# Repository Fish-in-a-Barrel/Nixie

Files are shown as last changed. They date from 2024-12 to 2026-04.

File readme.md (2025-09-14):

# Yet Another Nixie Clock

https://github.com/user-attachments/assets/0fcae77a-54a8-4b7d-9e90-6edd31807fbd

## Introduction

This is my Nixie clock project. It was created as an excuse to learn more about electronics and it touches on power circuits, microcontrollers, serial communications, and more.

The clock runs 12 IN-12A Nixie tubes that display the time and date. INS-1 tubes are used for digit separators. It also includes:
- USB-C PD power input
- Boost converter to provide 180V for the nixie tubes
- GPS module for date/time synchronization
- User-selectable timezone
- RTC module for precision timekeeping, and power-off timekeeping
- 128x32 mono OLED display for diagnostics
- Rotary encoder for user input
- I2C Driver boards for each tube

## Development Tools
**Hardware**: KiCad 8
**Firmware**: MPLAB X IDE

## Architecture
Architecture BlockDiagram

### Main Processor
A [Microchip PIC16F15224](https://ww1.microchip.com/downloads/aemDocuments/documents/MCU08/ProductDocuments/DataSheets/PIC16F15213-14-23-24-43-44-Microcontroller-Data-Sheet-40002195.pdf) 8-bit microcontroller is the main processing unit of the clock. It controls the boost converter while managing and coordinating the other hardware modules.

### Power
Power

A [Diodes Incorporated AP33772](https://www.diodes.com/assets/Datasheets/products_inactive_data/AP33772.pdf) is used to negotiate with a PD source for the input power. The AP33772 is controlled by the main MCU via I2C. The AP33772 requests 12V from the power source, which supplies the boost converter.

The AP33772 also provides a dedicated 5V power source. This is a low current source, so it is only used to drive the MCU and UI, which are needed during power-up. A separate 78L05 regulator (powered by the 12V from USB VBUS) provides 5V power to all of the other devices.

Finally, the AP33772 provides over-current and over-voltage protection features.

### User Interface
A 128x32 OLED display (driven by an [SSD1306](https://cdn-shop.adafruit.com/datasheets/SSD1306.pdf)) is used to display status and diagnostics information. A rotary encoder with detent is used to scroll through the different display pages, and to select timezone and DST support. The OLED pixel data is sent over I2C.

### Real Time Clock
A [DS3231](https://www.analog.com/media/en/technical-documentation/data-sheets/ds3231.pdf) RTC module provides an accurate time source for the clock. It is the source of the time/date displayed and is only updated if it differs from the GPS time. The RTC module is also equiped with a battery backup. This allows the clock to display time/date immediately after power-on instead of having to wait several minutes for valid GPS data. RTC data is sent over I2C.

### GPS
The [U-Blox NEO-6M](https://content.u-blox.com/sites/default/files/products/documents/NEO-6_DataSheet_%28GPS.G6-HW-09005%29.pdf) GPS module provides a reference time to initialize the RTC. The module streams standard NMEA messages to the primary MCU over UART serial. Time/date are decoded from these messages.

### Nixie Drivers
Each Nixie tube has a driver board. This board has a [Microchip PIC16F15243](https://ww1.microchip.com/downloads/aemDocuments/documents/MCU08/ProductDocuments/DataSheets/PIC16F15213-14-23-24-43-44-Microcontroller-Data-Sheet-40002195.pdf) MCU in I2C client mode receiving commands from the primary MCU. This client MCU drives the Nixie pins and provides features such as digit cross-fading and cathode maintenance.

## Project Components

### ClockController
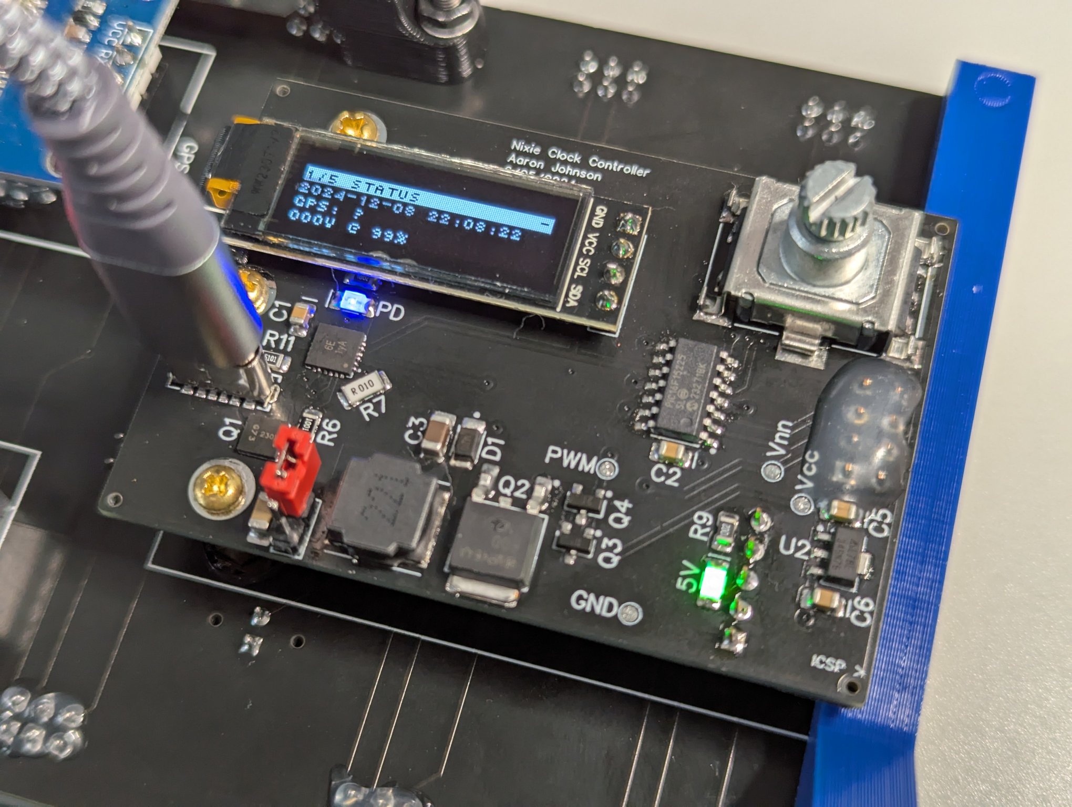
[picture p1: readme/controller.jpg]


This is the main controller board. It connects to a header on the back of the display board and has these main components:
- Primary MCU
- USB PD components
- Boost converter circuitry
- User Interface

### Hardware / Display Board
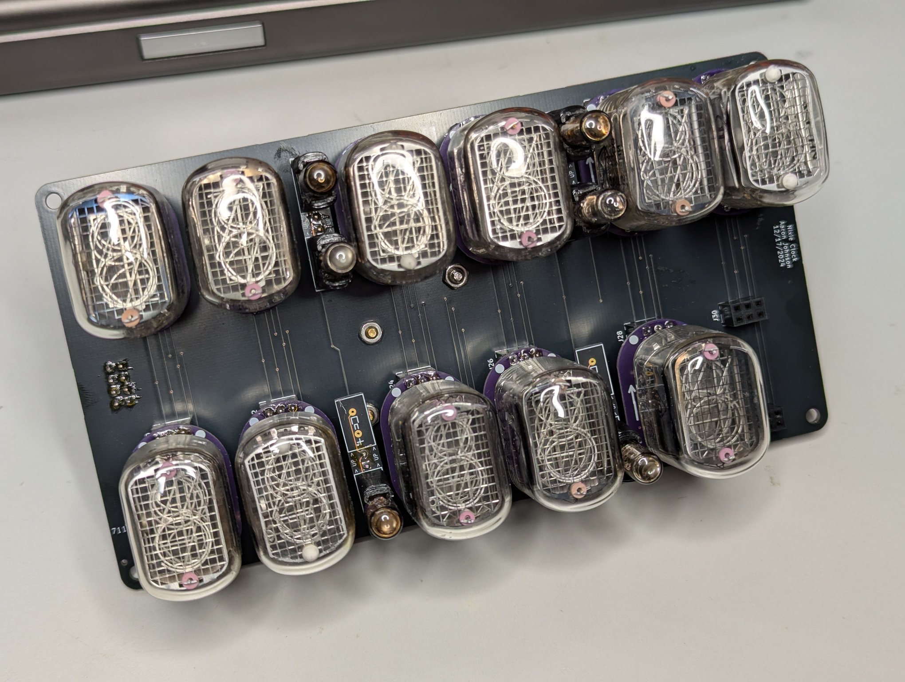
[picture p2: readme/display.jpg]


This board servers as the main support structure of the clock. The Nixie drivers connect to headers on the front of the board. The controller board, GPS, and RTC all connect to the back of the board.

### NixieDriver
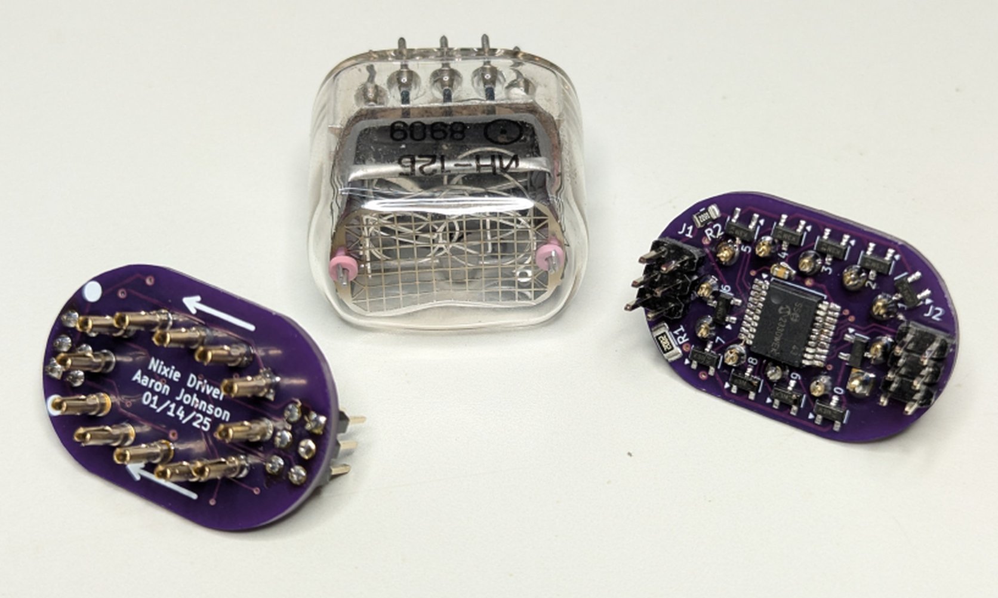
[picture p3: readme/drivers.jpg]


The driver board for each individual IN-12 Nixie tube.

### NixieDriverTester
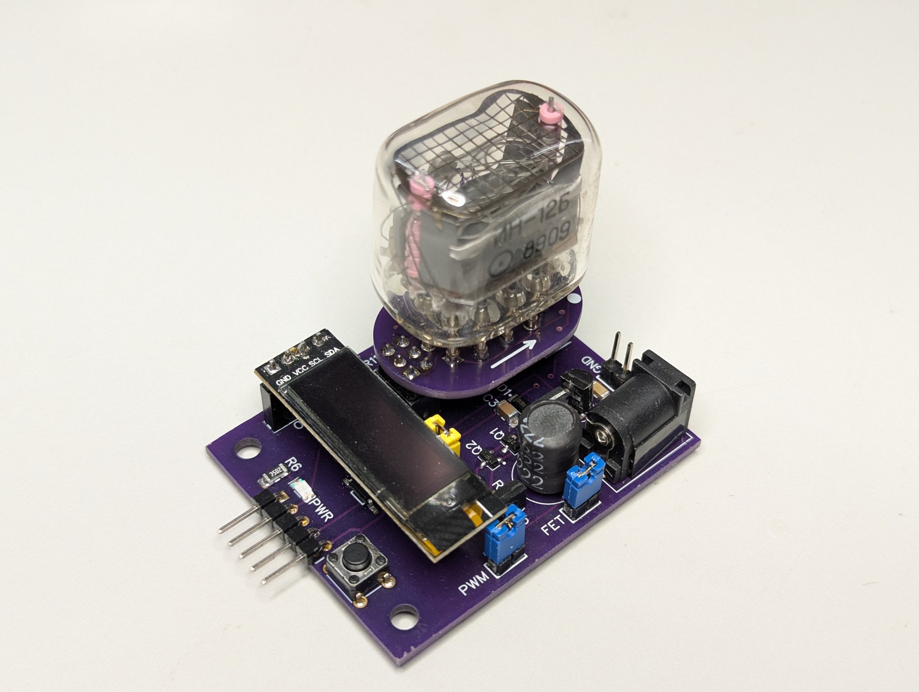
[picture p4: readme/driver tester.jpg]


This is a stand-alone test board that will power and exercise a single NixieDriver and tube. It is used for QA of assembled driver boards and testing of the NixieDriver firmware.

### Hardware / Nixie Driver ICSP Adapter
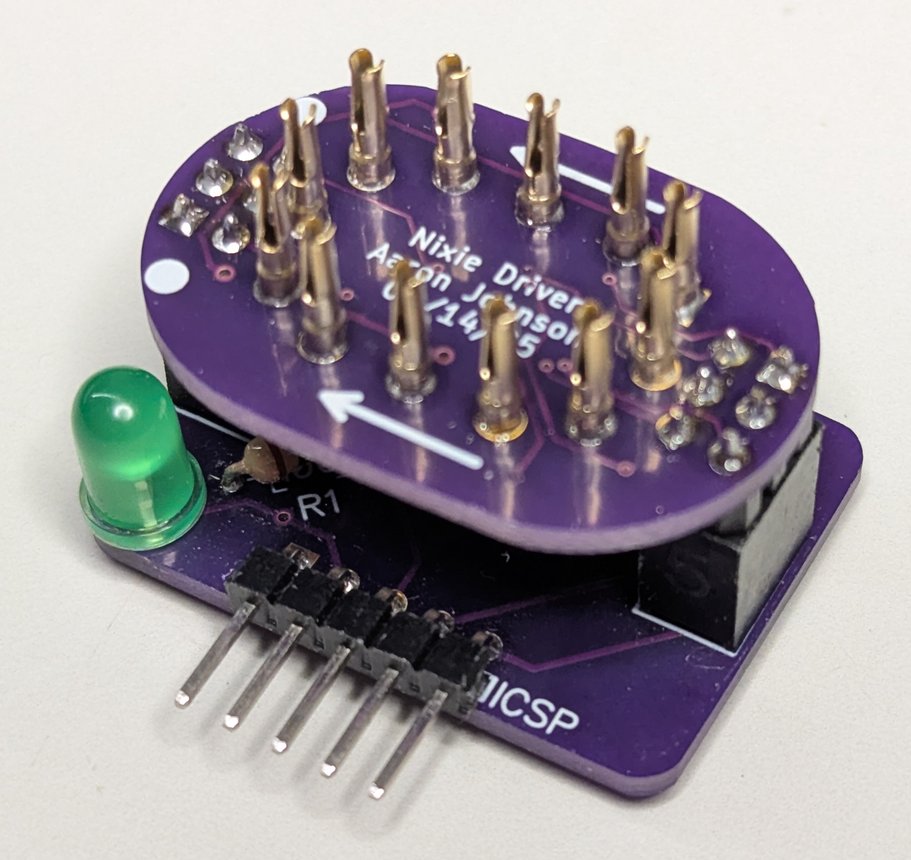
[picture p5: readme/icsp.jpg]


A small board that attaches to a NixieDriver and provides a pin-out compatible with a PICKIT 5 programmer for In Circuit Serial Programming.

### Hardware / Separator
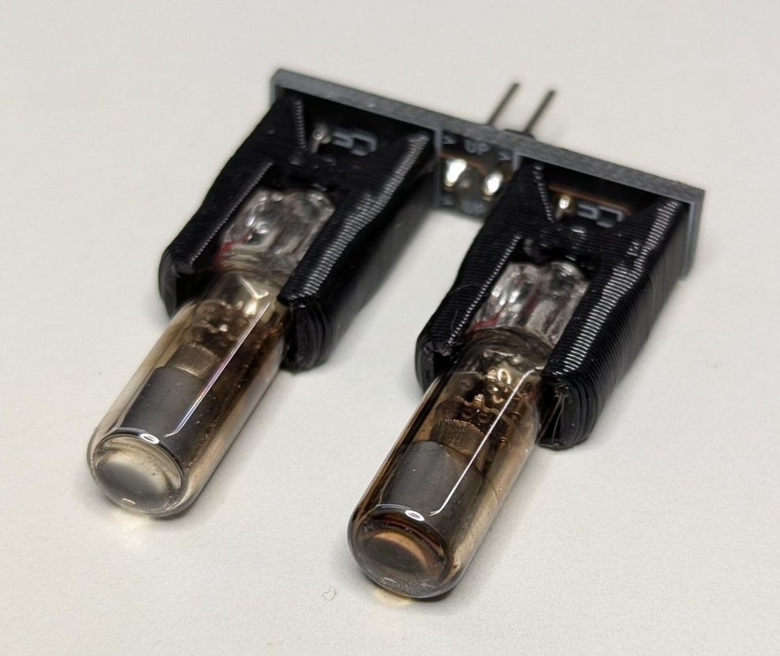
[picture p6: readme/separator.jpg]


A tiny board that adapts the physical interface of the INS-1 tubes used as digit separators.

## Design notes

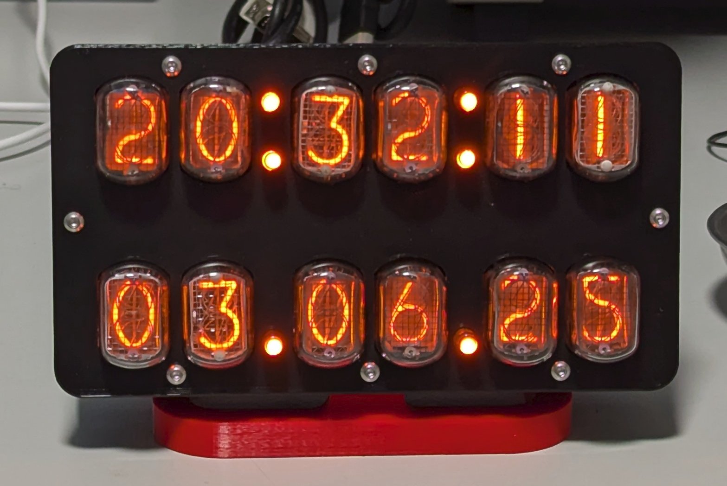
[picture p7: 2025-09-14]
readme/clock.jpg

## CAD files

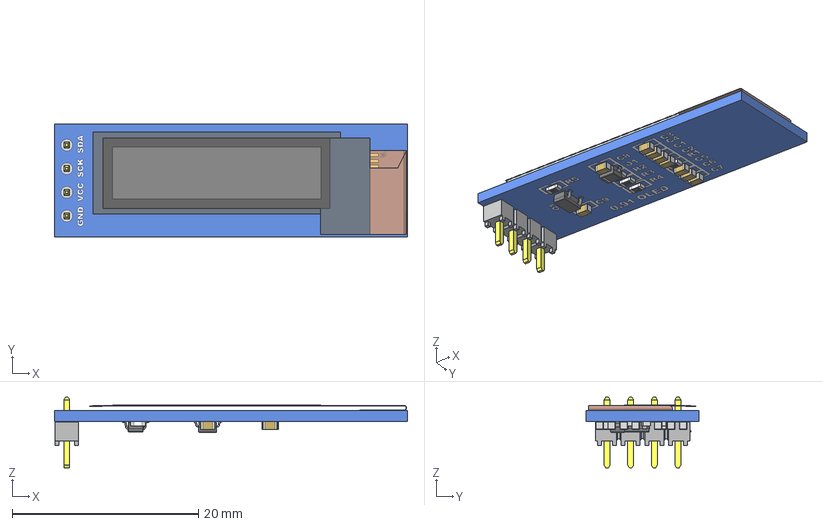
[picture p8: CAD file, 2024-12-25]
Hardware/3D/0.91in OLED.step
37.9 x 12.1 x 7.62 mm
0603 Resistor_2
0.91in OLED - Folded Flush - Without Glass x 2
0603 Capacitor
0603 Capacitor_5
0603 Capacitor_8
SOT23-3
0603 Resistor_4
0603 Capacitor_6
TSW-104-06-T-S_body
0603 Capacitor_4
0603 Capacitor_2
0603 Capacitor_7
Diode (SOD-323)
0603 Resistor_1
0603 Resistor_3
0603 Resistor
T-1S6-18-TSW-1-06-4-S
0603 Capacitor_1
0.91in oled Module - Board
0603 Capacitor_3

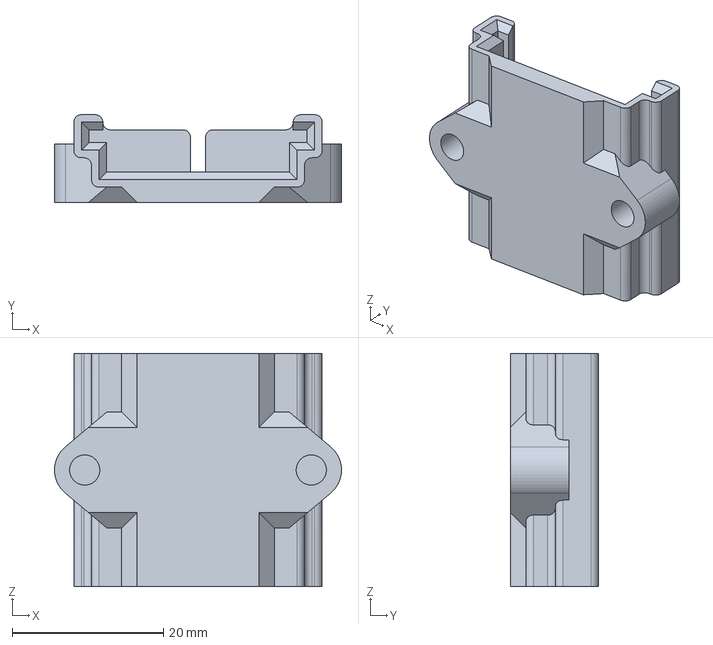
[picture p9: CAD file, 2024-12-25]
Hardware/3D/GPS Antenna Holder.step
38.0 x 11.6 x 30.9 mm

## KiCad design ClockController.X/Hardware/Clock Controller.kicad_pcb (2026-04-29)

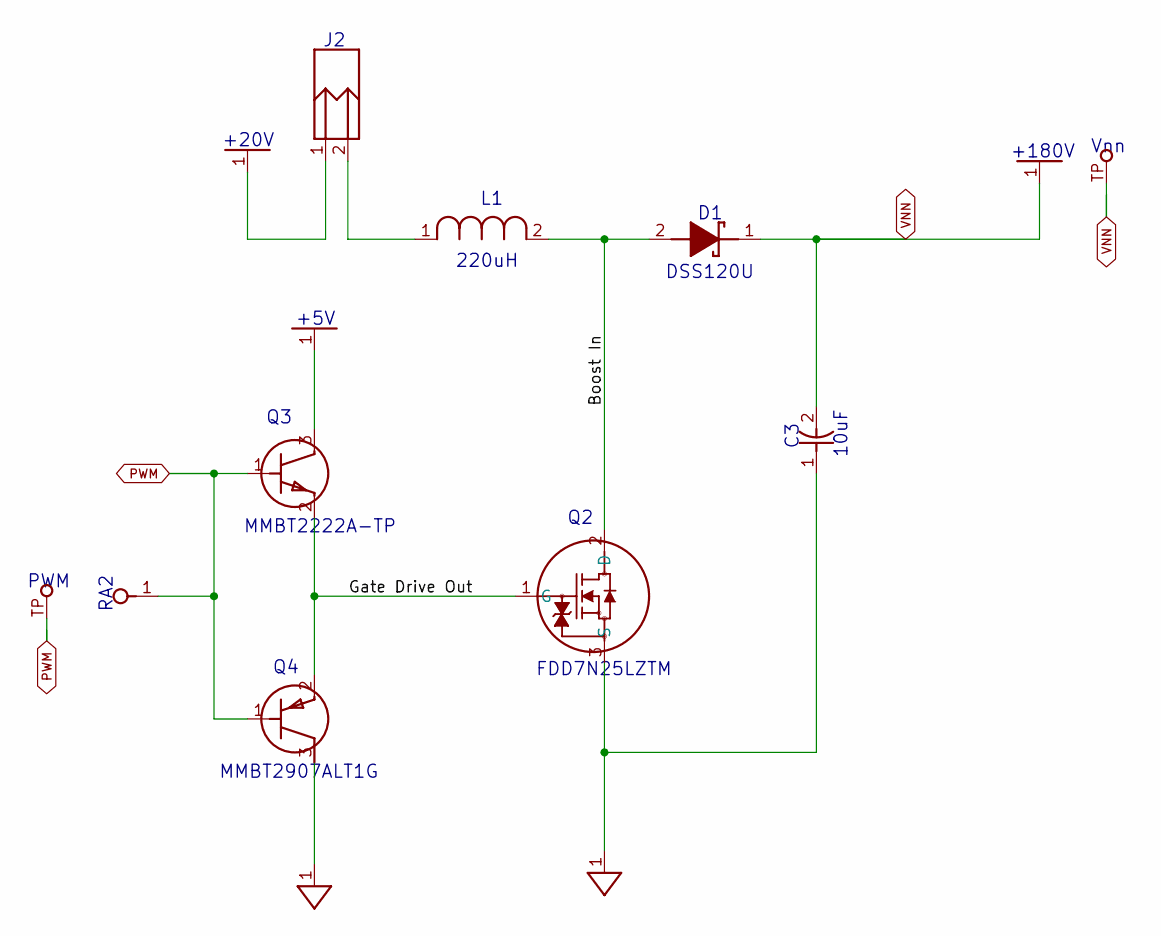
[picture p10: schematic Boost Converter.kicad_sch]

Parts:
C3: 10uF; C_1812_4532Metric
D1: SMD220PL; D_SOD-123F
J2: HDR-1X2H; PinHeader_1x02_P2.54mm_Horizontal
L1: 220uH; SRN8040TA221M
PWM0: Most Density; TP_1.25MM
Q2: FDD7N25LZTM; TO-252-2
Q3: MMBT2222A-TP; SOT-23
Q4: MMBT2907ALT1G; SOT-23
Vnn0: Most Density; TP_1.25MM

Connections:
+5V: Q3.3 (C); also elsewhere on the board
+20V: J2.1; also elsewhere on the board
/Boost Converter/Boost In: D1.2 (A), L1.2, Q2.2 (D)
/Boost Converter/Gate Drive Out: Q2.1 (G), Q3.2 (E), Q4.2 (E)
GND: C3.1, Q2.3 (S), Q4.3 (C); also elsewhere on the board
unnamed: J2.2, L1.1
PWM: PWM0.TP, Q3.1 (B), Q4.1 (B); also elsewhere on the board
VNN: C3.2, D1.1 (K), Vnn0.TP; also elsewhere on the board

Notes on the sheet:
MMBT2222A-TP
FDD7N25LZTM
+180V
PWM
DSS120U
Vnn
RA2
MMBT2907ALT1G
220uH
+5V
+20V
10uF

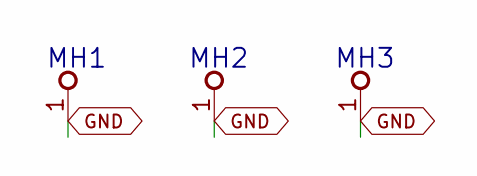
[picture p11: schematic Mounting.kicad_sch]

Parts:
MH1, MH2, MH3: M2.5_MTGP540H285

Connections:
GND: MH1.1, MH2.1, MH3.1; also elsewhere on the board

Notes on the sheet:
MH1
MH3
MH2

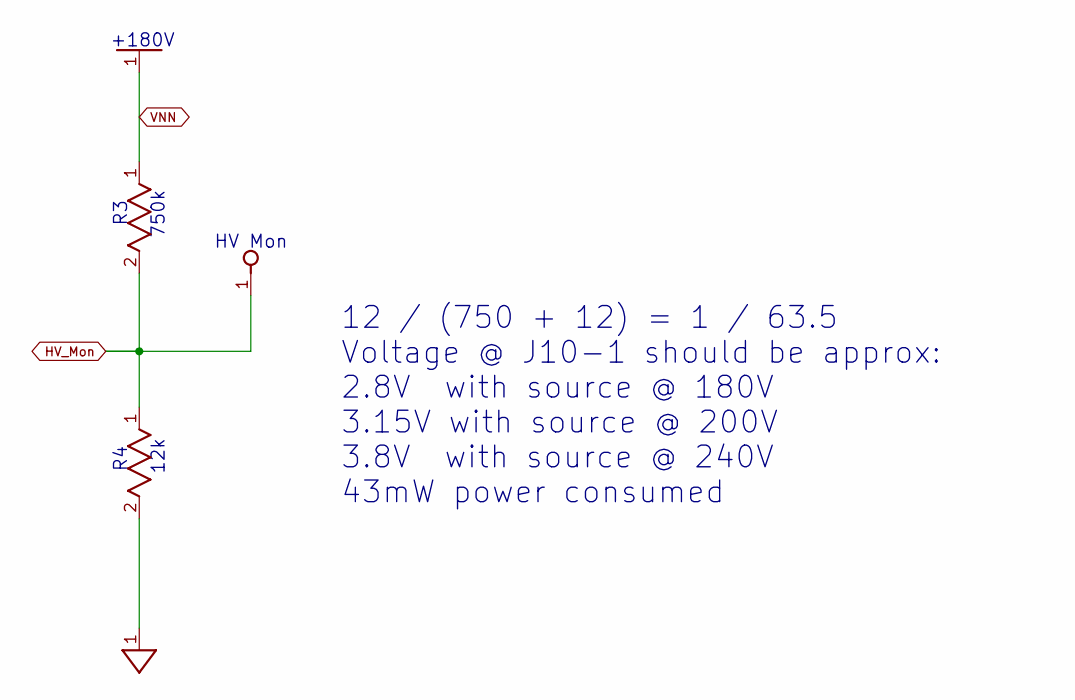
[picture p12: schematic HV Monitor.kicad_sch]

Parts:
R3: 750k; R_0805_2012Metric
R4: 12k; R_0805_2012Metric

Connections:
GND: R4.2; also elsewhere on the board
HV_Mon: R3.2, R4.1; also elsewhere on the board
VNN: R3.1; also elsewhere on the board

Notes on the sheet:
12 / (750 + 12) = 1 / 63.5 Voltage @ J10-1 should be approx: 2.8V with source @ 180V 3.15V with source @ 200V 3.8V with source @ 240V 43mW power consumed
+180V
HV Mon
12k
750k

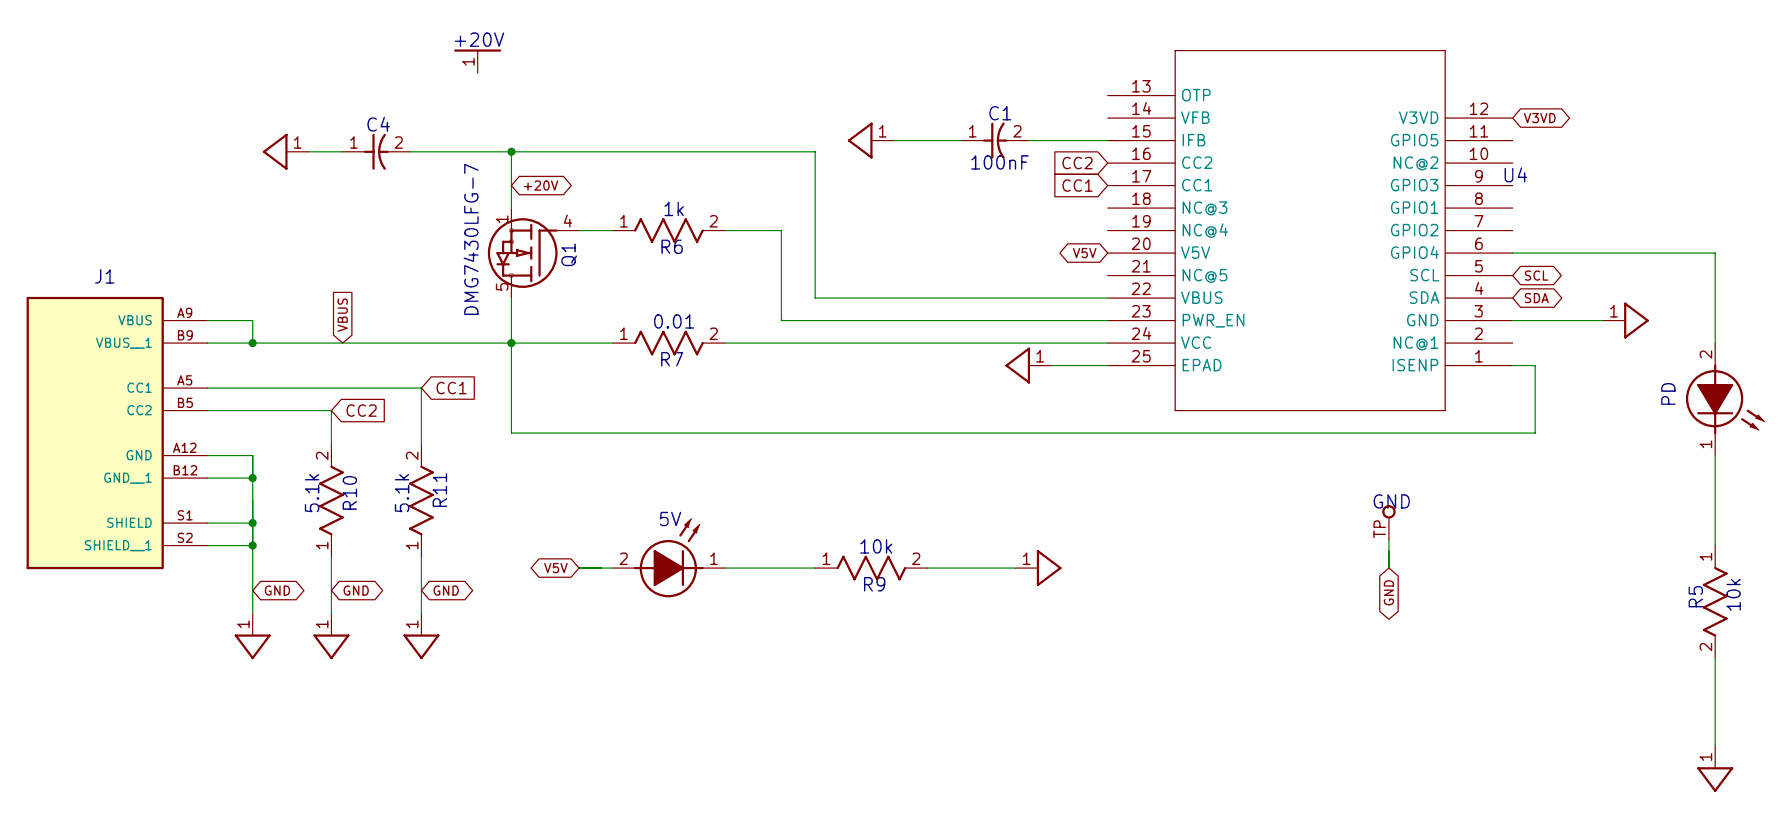
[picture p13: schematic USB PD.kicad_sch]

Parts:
C1: 100nF; C_0805_2012Metric
C4: 1uF; C_1206_3216Metric
GND0: Most Density; TP_1.25MM
J1: UJC-VP-3-SMT-TR; CUI_UJC-VP-3-SMT-TR; PARTREV 1.0
PD0: LED_1206(3216_METRIC)_N_BLUE; LED_1206_3216Metric
Q1: DMG7430LFG-7; PowerDI3333-8
R5, R9: 10k; R_0603_1608Metric
R6: 1k; R_0805_2012Metric
R7: 0.01; R_1206_3216Metric
R10, R11: 5.1k; R_0603_1608Metric
U4: AP33772DKZ-13; QFN-24-1EP_4x4mm_P0.5mm_EP2.7x2.7mm
UNK5V0: LED_1206(3216_METRIC)_N_GREEN; LED_1206_3216Metric

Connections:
+20V: C4.2, Q1.1 (S), Q1.2 (S), Q1.3 (S), U4.22 (VBUS); also elsewhere on the board
CC1: J1.A5 (CC1), R11.2, U4.17 (CC1)
CC2: J1.B5 (CC2), R10.2, U4.16 (CC2)
GND: C1.1, C4.1, GND0.TP, J1.A12 (GND), J1.B12 (GND__1), J1.S1 (SHIELD), J1.S2 (SHIELD__1), R5.2, R9.2, R10.1, R11.1, U4.3 (GND), U4.25 (EPAD); also elsewhere on the board
unnamed: PD0.2 (A), U4.6 (GPIO4)
unnamed: PD0.1 (K), R5.1
unnamed: Q1.4 (G), R6.1
unnamed: C1.2, U4.15 (IFB)
unnamed: R6.2, U4.23 (PWR_EN)
unnamed: R7.2, U4.24 (VCC)
unnamed: R9.1, UNK5V0.1 (K)
SCL: U4.5 (SCL); also elsewhere on the board
SDA: U4.4 (SDA); also elsewhere on the board
V3VD: U4.12 (V3VD)
V5V: U4.20 (V5V), UNK5V0.2 (A); also elsewhere on the board
VBUS: J1.A9 (VBUS), J1.B9 (VBUS__1), Q1.5 (D), Q1.6 (D), Q1.7 (D), Q1.8 (D), R7.1, U4.1 (ISENP)

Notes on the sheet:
0.01
R10
10k
+20V
5.1k
R11
GND
100nF
DMG7430LFG-7

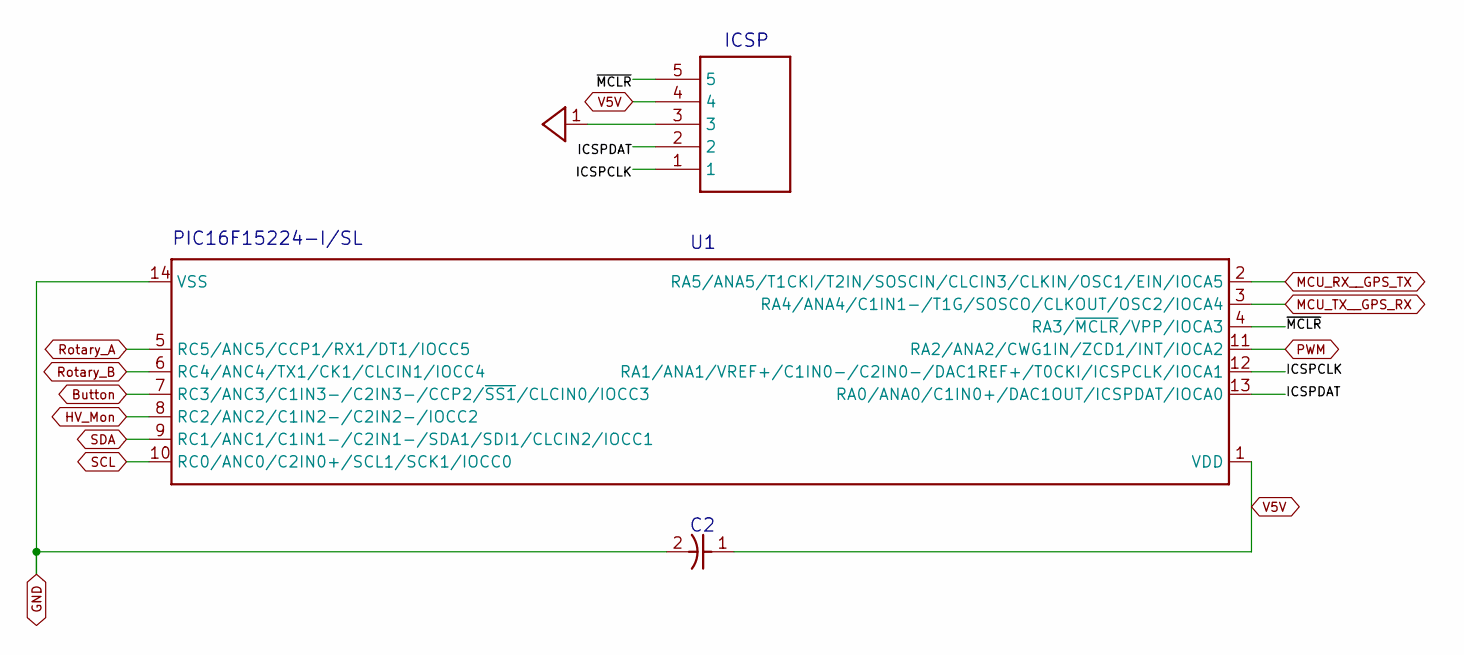
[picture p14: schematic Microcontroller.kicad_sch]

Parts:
C2: 100nF; C_0805_2012Metric
ICSP0: PPPC051LGBN-RC; PinSocket_1x05_P2.54mm_Horizontal
U1: PIC16F15224-I/SL; SOIC14P127_869X599X175L84X42N

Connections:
/Microcontroller/ICSPCLK: ICSP0.1, U1.12 (RA1/ANA1/VREF+/C1IN0-/C2IN0-/DAC1REF+/T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)
/Microcontroller/ICSPDAT: ICSP0.2, U1.13 (RA0/ANA0/C1IN0+/DAC1OUT/ICSPDAT/IOCA0)
/Microcontroller/~MCLR: ICSP0.5, U1.4 (RA3/~MCLR/VPP/IOCA3)
Button: U1.7 (RC3/ANC3/C1IN3-/C2IN3-/CCP2/~SS1/CLCIN0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); also elsewhere on the board
GND: C2.2, ICSP0.3, U1.14 (VSS); also elsewhere on the board
HV_Mon: U1.8 (RC2/ANC2/C1IN2-/C2IN2-/IOCC2); also elsewhere on the board
MCU_RX__GPS_TX: U1.2 (RA5/ANA5/T1CKI/T2IN/SOSCIN/CLCIN3/CLKIN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); also elsewhere on the board
MCU_TX__GPS_RX: U1.3 (RA4/ANA4/C1IN1-/T1G/SOSCO/CLKOUT/OSC2/I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); also elsewhere on the board
PWM: U1.11 (RA2/ANA2/CWG1IN/ZCD1/INT/IOCA2); also elsewhere on the board
Rotary_A: U1.5 (RC5/ANC5/CCP1/RX1/DT1/IOCC5); also elsewhere on the board
Rotary_B: U1.6 (RC4/ANC4/TX1/CK1/CLCIN1/IOCC4); also elsewhere on the board
SCL: U1.10 (RC0/ANC0/C2IN0+/SCL1/SCK1/IOCC0); also elsewhere on the board
SDA: U1.9 (RC1/ANC1/C1IN1-/C2IN1-/SDA1/SDI1/CLCIN2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); also elsewhere on the board
V5V: C2.1, ICSP0.4, U1.1 (VDD); also elsewhere on the board

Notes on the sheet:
PIC16F15224-I/SL
ICSP

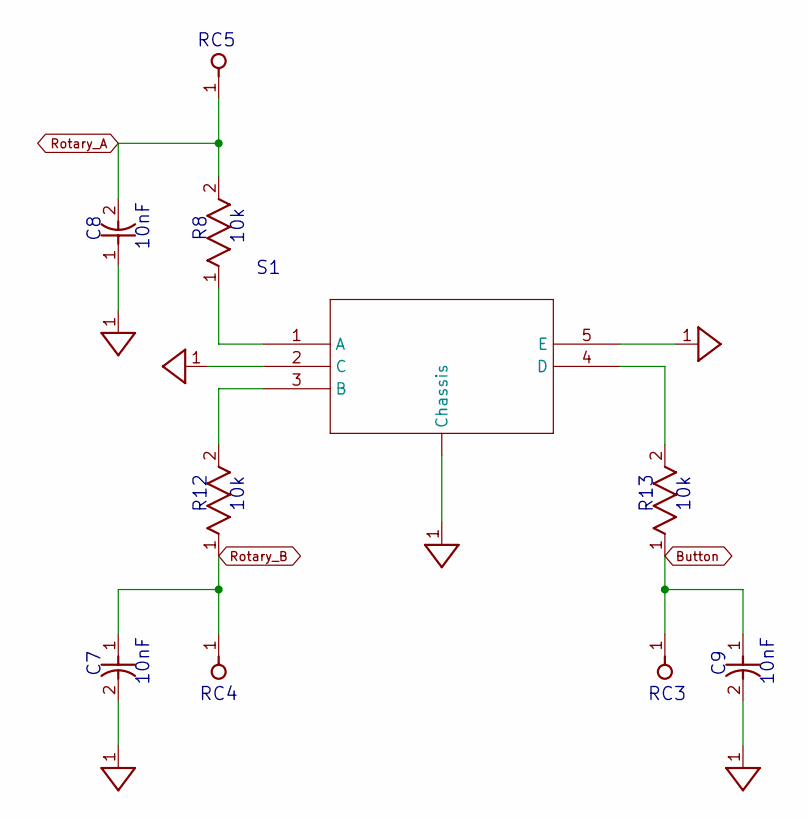
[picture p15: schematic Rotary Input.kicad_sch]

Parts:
C7, C8, C9: 10nF; C_0603_1608Metric
R8, R12, R13: 10k; R_0603_1608Metric
S1: PEC11S-929K-S0015

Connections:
Button: C9.1, R13.1; also elsewhere on the board
GND: C7.2, C8.1, C9.2, S1.2 (C), S1.5 (E), S1.10 (Chassis); also elsewhere on the board
unnamed: R8.1, S1.1 (A)
unnamed: R12.2, S1.3 (B)
unnamed: R13.2, S1.4 (D)
Rotary_A: C8.2, R8.2; also elsewhere on the board
Rotary_B: C7.1, R12.1; also elsewhere on the board

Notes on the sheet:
10k
10nF
R12
RC5
RC3
R13
RC4

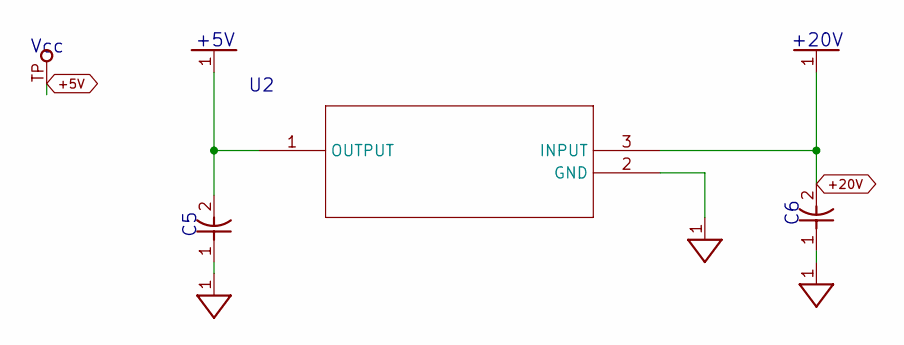
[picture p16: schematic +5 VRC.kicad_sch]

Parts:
C5, C6: 100nF; C_0805_2012Metric
U2: AS78L05RTR-E1; SOT-89-3
Vcc0: Most Density; TP_1.25MM

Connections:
+5V: C5.2, U2.1 (OUTPUT), Vcc0.TP; also elsewhere on the board
+20V: C6.2, U2.3 (INPUT); also elsewhere on the board
GND: C5.1, C6.1, U2.2 (GND); also elsewhere on the board

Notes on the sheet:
+20V
Vcc
+5V

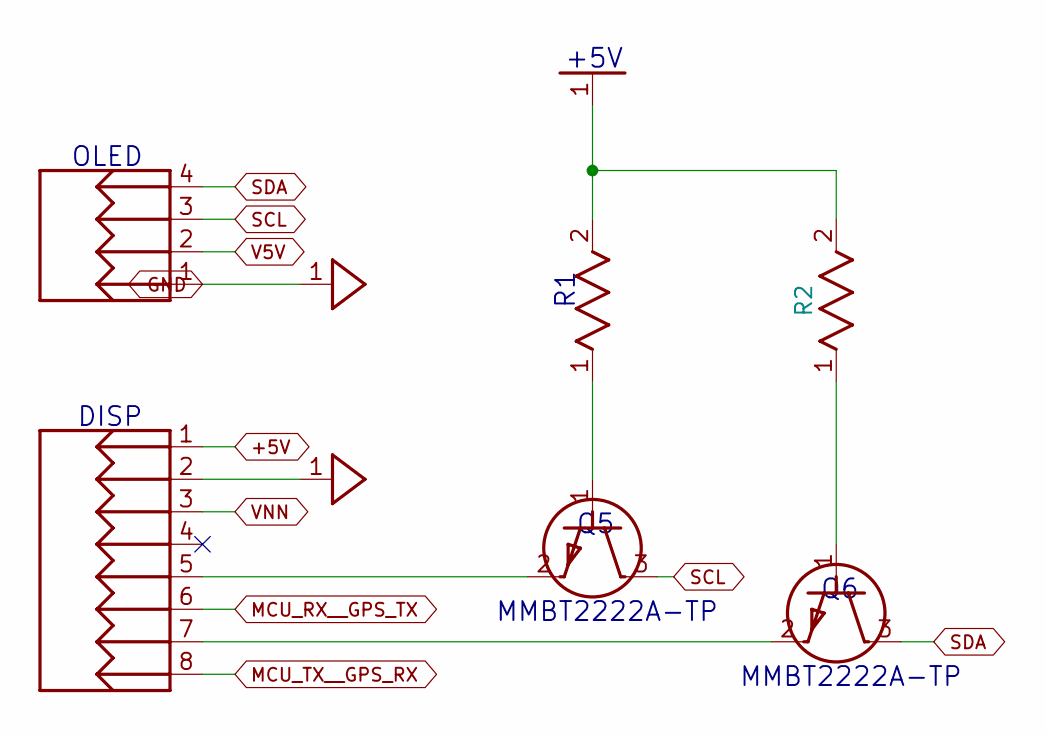
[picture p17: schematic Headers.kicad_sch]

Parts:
DISP0: HDR-2X4; PinHeader_2x04_P2.54mm_Vertical
OLED0: HDR-1X4; SSD1306 0.91 128x32 OLED
Q5, Q6: MMBT2222A-TP; SOT-23
R1, R2: 2.2k; R_0603_1608Metric

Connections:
+5V: DISP0.1, R1.2, R2.2; also elsewhere on the board
GND: DISP0.2, OLED0.1; also elsewhere on the board
MCU_RX__GPS_TX: DISP0.6; also elsewhere on the board
MCU_TX__GPS_RX: DISP0.8; also elsewhere on the board
unnamed: DISP0.5, Q5.2 (E)
unnamed: DISP0.7, Q6.2 (E)
unnamed: Q5.1 (B), R1.1
unnamed: Q6.1 (B), R2.1
SCL: OLED0.3, Q5.3 (C); also elsewhere on the board
SDA: OLED0.4, Q6.3 (C); also elsewhere on the board
V5V: OLED0.2; also elsewhere on the board
VNN: DISP0.3; also elsewhere on the board

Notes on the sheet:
DISP
OLED
+5V
MMBT2222A-TP

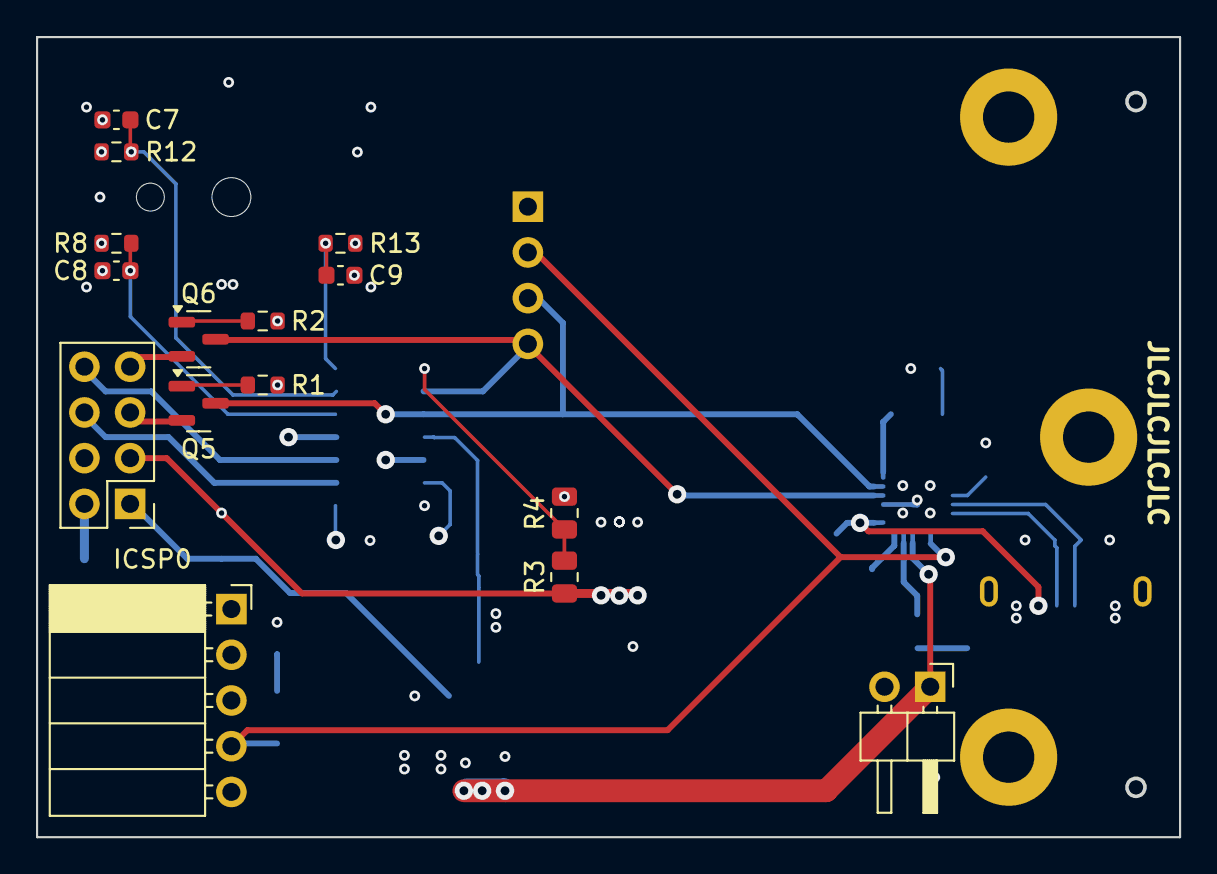
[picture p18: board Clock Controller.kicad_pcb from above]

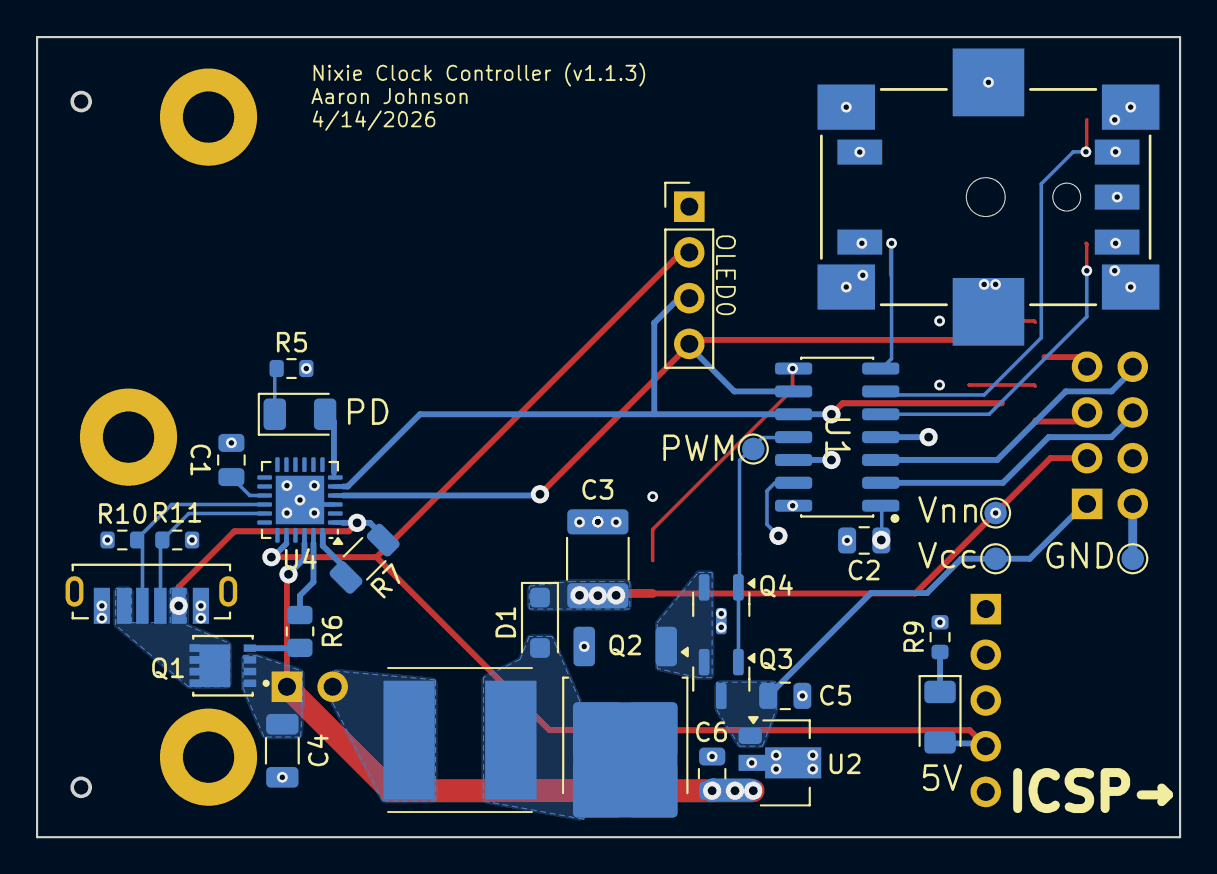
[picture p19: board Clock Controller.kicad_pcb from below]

Board: 4 copper layers, 63.5 x 44.5 mm, 48 parts (30 on the bottom side), 37 nets.

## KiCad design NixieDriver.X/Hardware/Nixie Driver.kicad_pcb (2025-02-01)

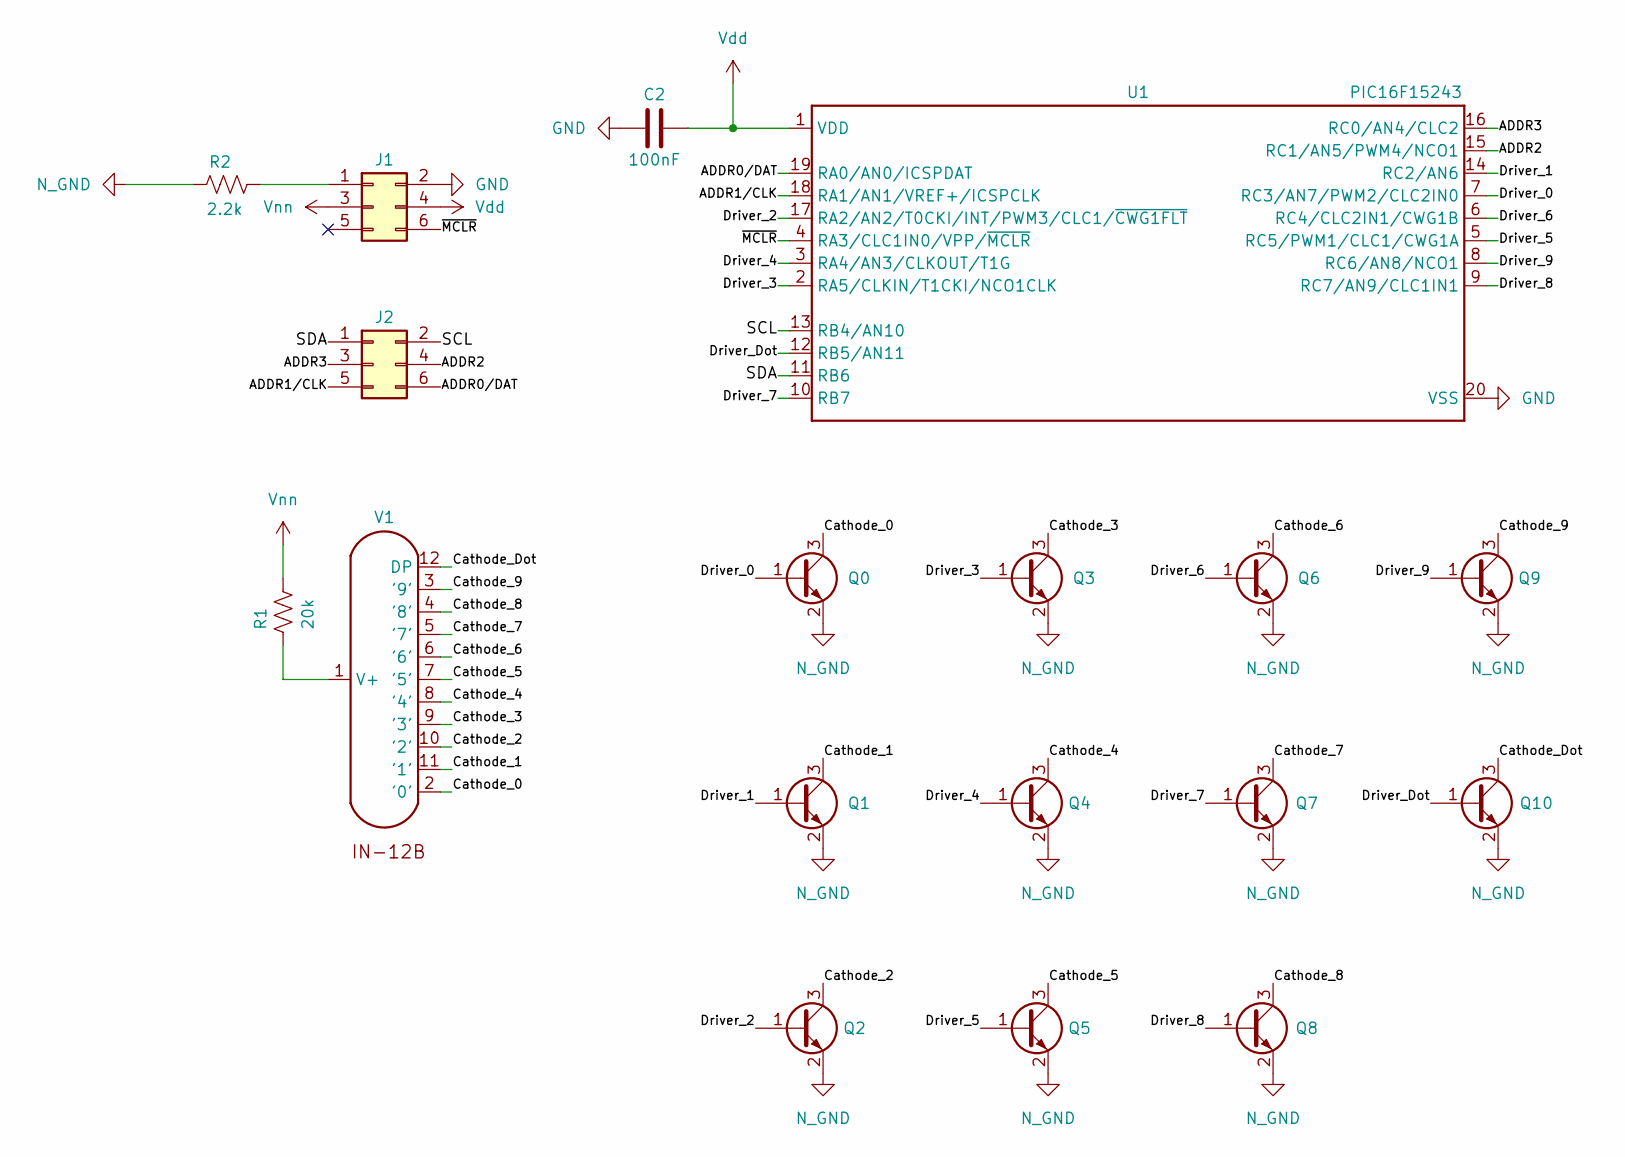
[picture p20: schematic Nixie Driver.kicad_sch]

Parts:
C2: 100nF; C_0603_1608Metric
J1, J2: Conn_02x03_Odd_Even; PinHeader_2x03_P2.54mm_Vertical
Q0, Q1, Q2, Q3, Q4, Q5, Q6, Q7, Q8, Q9, Q10: MMBTA42LT1G; SOT-23
R1: 20k; R_1206_3216Metric
R2: 2.2k; R_0805_2012Metric
U1: PIC16F15243; SSOP-20_5.3x7.2mm_P0.65mm
V1: IN-12B; IN-12[A_B]

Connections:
/ADDR0/DAT: J2.6, U1.19 (RA0/AN0/ICSPDAT)
/ADDR1/CLK: J2.5, U1.18 (RA1/AN1/VREF+/ICSPCLK)
/ADDR2: J2.4, U1.15 (RC1/AN5/PWM4/NCO1)
/ADDR3: J2.3, U1.16 (RC0/AN4/CLC2)
/Cathode_0: Q0.3 (C), V1.2 ('0')
/Cathode_1: Q1.3 (C), V1.11 ('1')
/Cathode_2: Q2.3 (C), V1.10 ('2')
/Cathode_3: Q3.3 (C), V1.9 ('3')
/Cathode_4: Q4.3 (C), V1.8 ('4')
/Cathode_5: Q5.3 (C), V1.7 ('5')
/Cathode_6: Q6.3 (C), V1.6 ('6')
/Cathode_7: Q7.3 (C), V1.5 ('7')
/Cathode_8: Q8.3 (C), V1.4 ('8')
/Cathode_9: Q9.3 (C), V1.3 ('9')
/Cathode_Dot: Q10.3 (C), V1.12 (DP)
/Driver_0: Q0.1 (B), U1.7 (RC3/AN7/PWM2/CLC2IN0)
/Driver_1: Q1.1 (B), U1.14 (RC2/AN6)
/Driver_2: Q2.1 (B), U1.17 (RA2/AN2/T0CKI/INT/PWM3/CLC1/~CWG1FLT)
/Driver_3: Q3.1 (B), U1.2 (RA5/CLKIN/T1CKI/NCO1CLK)
/Driver_4: Q4.1 (B), U1.3 (RA4/AN3/CLKOUT/T1G)
/Driver_5: Q5.1 (B), U1.5 (RC5/PWM1/CLC1/CWG1A)
/Driver_6: Q6.1 (B), U1.6 (RC4/CLC2IN1/CWG1B)
/Driver_7: Q7.1 (B), U1.10 (RB7)
/Driver_8: Q8.1 (B), U1.9 (RC7/AN9/CLC1IN1)
/Driver_9: Q9.1 (B), U1.8 (RC6/AN8/NCO1)
/Driver_Dot: Q10.1 (B), U1.12 (RB5/AN11)
/SCL: J2.2, U1.13 (RB4/AN10)
/SDA: J2.1, U1.11 (RB6)
/~MCLR: J1.6, U1.4 (RA3/CLC1IN0/VPP/~MCLR)
GND: C2.2, J1.2, U1.20 (VSS)
N_GND: Q0.2 (E), Q1.2 (E), Q2.2 (E), Q3.2 (E), Q4.2 (E), Q5.2 (E), Q6.2 (E), Q7.2 (E), Q8.2 (E), Q9.2 (E), Q10.2 (E), R2.1
unnamed: J1.1, R2.2
unnamed: R1.1, V1.1 (V+)
Vdd: C2.1, J1.4, U1.1 (VDD)
Vnn: J1.3, R1.2

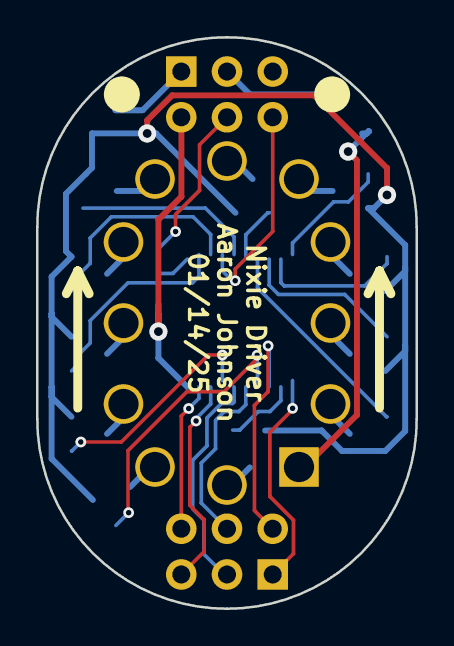
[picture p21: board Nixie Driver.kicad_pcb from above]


Board: 2 copper layers, 21.1 x 31.8 mm, 18 parts (17 on the bottom side), 35 nets.

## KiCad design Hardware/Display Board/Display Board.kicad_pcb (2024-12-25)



Board: 2 copper layers, 165.1 x 88.9 mm, 45 parts (4 on the bottom side), 7 nets.

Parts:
AE1: Antenna; GPS Antenna Holder
H1, H4, H7: MountingHole_Pad; MountingHole_2.5mm_Pad
H2, H5: MountingHole; MountingHole_2.5mm
H3, H6, H8, H9, H10, H11, H12, H13: MountingHole; MountingHole_3.2mm_M3
J1: GPS; PinSocket_1x04_P2.54mm_Vertical
J2: RTC; PinSocket_1x04_P2.54mm_Vertical
J3: CONTROLLER; PinSocket_2x04_P2.54mm_Vertical
J4: H:M; PinSocket_1x02_P2.54mm_Vertical
J5: M:D; PinSocket_1x02_P2.54mm_Vertical
J6: M:S; PinSocket_1x02_P2.54mm_Vertical
J7: D:Y; PinSocket_1x02_P2.54mm_Vertical
J8, J9, J10, J11, J12, J13, J14, J15, J16, J17, J18, J19, J20, J21, J22, J23, J24, J25, J26, J27, J28, J29, J30, J31: Conn_02x03_Odd_Even; PinSocket_2x03_P2.54mm_Vertical

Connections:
GND: H1.1, H4.1, H7.1, J1.1, J2.1, J3.2, J4.1, J5.1, J6.1, J7.1, J8.1, J8.2, J9.3, J9.4, J9.5, J10.1, J10.2, J11.3, J11.4, J11.6, J12.1, J12.2, J13.3, J13.4, J14.1, J14.2, J15.3, J15.5, J15.6, J16.1, J16.2, J17.3, J17.5, J18.1, J18.2, J19.3, J19.6, J20.1, J20.2, J21.4, J22.1, J22.2, J23.5, J23.6, J24.1, J24.2, J25.4, J25.5, J26.1, J26.2, J27.4, J27.6, J28.1, J28.2, J29.5, J30.1, J30.2, J31.6
MCU RX / GPS TX: J1.2, J3.6
MCU TX / GPS RX: J1.3, J3.8
SCL: J2.4, J3.5, J9.2, J11.2, J13.2, J15.2, J17.2, J19.2, J21.2, J23.2, J25.2, J27.2, J29.2, J31.2
SDA: J2.3, J3.7, J9.1, J11.1, J13.1, J15.1, J17.1, J19.1, J21.1, J23.1, J25.1, J27.1, J29.1, J31.1
Vdd: J1.4, J2.2, J3.1, J8.4, J10.4, J12.4, J14.4, J16.4, J18.4, J20.4, J22.4, J24.4, J26.4, J28.4, J30.4
Vnn: J3.3, J4.2, J5.2, J6.2, J7.2, J8.3, J10.3, J12.3, J14.3, J16.3, J18.3, J20.3, J22.3, J24.3, J26.3, J28.3, J30.3

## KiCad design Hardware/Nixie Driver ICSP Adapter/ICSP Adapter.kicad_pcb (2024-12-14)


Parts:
ICSP0: HDR-1X5H; PinHeader_1x05_P2.54mm_Horizontal
NIX1, NIX2: HDRF-2X3; PinHeader_2x03_P2.54mm_Vertical
PWR0: LED-5MM_ROUND_GREEN; LED_D5.0mm
R1: 100; R_Axial_DIN0207_L6.3mm_D2.5mm_P7.62mm_Horizontal

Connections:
GND: ICSP0.3, NIX1.6, R1.2
LED: PWR0.1 (K), R1.1
SCLK: ICSP0.5, NIX2.6
SDAT: ICSP0.4, NIX2.5
VDD: ICSP0.2, NIX1.4, PWR0.2 (A)
~MCLR: ICSP0.1, NIX1.2

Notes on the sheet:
ICSP
NIX2
NIX1


Board: 2 copper layers, 24.1 x 33.7 mm, 5 parts (0 on the bottom side), 6 nets.

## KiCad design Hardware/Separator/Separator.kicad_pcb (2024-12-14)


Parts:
J1: Conn_01x02; PinHeader_1x02_P2.54mm_Vertical
R1, R2: 200k; R_1206_3216Metric
V1, V2: Lamp_Neon; INS-1

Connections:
unnamed: J1.1, R1.2, R2.2
unnamed: J1.2, V1.2, V2.2
unnamed: R1.1, V1.1
unnamed: R2.1, V2.1



Board: 2 copper layers, 6.3 x 27.9 mm, 5 parts (3 on the bottom side), 4 nets.

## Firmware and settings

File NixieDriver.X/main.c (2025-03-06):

//
// Section references are to the "PIC16F15213/14/23/24/43/44 Low Pin Count Microcontrollers" datasheet.
// Document DS40002195D
// https://ww1.microchip.com/downloads/aemDocuments/documents/MCU08/ProductDocuments/DataSheets/PIC16F15213-14-23-24-43-44-Microcontroller-Data-Sheet-40002195.pdf
//

#include <xc.h>
#include "clock.h"
#include "pps_inputs.h"
#include "pps_outputs.h"

// The pin GPIO register for each cathode driver.
#define CATHODE_0_PIN RC3
#define CATHODE_9_PIN RC6
#define CATHODE_8_PIN RC7
#define CATHODE_7_PIN RB7
#define CATHODE_6_PIN RC4
#define CATHODE_5_PIN RC5
#define CATHODE_4_PIN RA4
#define CATHODE_3_PIN RA5
#define CATHODE_2_PIN RA2
#define CATHODE_1_PIN RC2
#define CATHODE_COMMA_PIN RB5

// The pin GPIO register for each address bit.
#define ADDRESS_PIN_0 RA0 // LSB
#define ADDRESS_PIN_1 RA1
#define ADDRESS_PIN_2 RC1
#define ADDRESS_PIN_3 RC0

// Note that this is shifted left by 1 bit for convenient use with the I2C registers.
#define I2C_ADDRESS (\
    (uint8_t)((uint8_t)ADDRESS_PIN_0 << 1) | \
    (uint8_t)((uint8_t)ADDRESS_PIN_1 << 2) | \
    (uint8_t)((uint8_t)ADDRESS_PIN_2 << 3) | \
    (uint8_t)((uint8_t)ADDRESS_PIN_3 << 4) )

// TOPPS(X) composites the pin register with the suffix "PPS" to form the PPS register associated with that pin.
//    eg: TOPPS(RA1) -> RA1PPS
#define TOPPS_(RA) RA ## PPS
#define TOPPS(RA) TOPPS_(RA)

typedef union
{
    uint8_t _raw;
    struct
    {
        uint8_t digit:4;
        uint8_t :3;
        uint8_t comma:1;
    };
} NixieCommand;

#define REFRESH_CATHODES_COMMAND 0xFF

#define Byte2NixieCommand(b) ((NixieCommand)(b))
#define Address2NixieCommand(a) Byte2NixieCommand((uint8_t)(((a >> 1) & 0x0F) | ((a << 3) & 0x80)))

// The PPS register for each driver pin.
#define CATHODE_1_PPS TOPPS(CATHODE_1_PIN)
#define CATHODE_2_PPS TOPPS(CATHODE_2_PIN)
#define CATHODE_3_PPS TOPPS(CATHODE_3_PIN)
#define CATHODE_4_PPS TOPPS(CATHODE_4_PIN)
#define CATHODE_5_PPS TOPPS(CATHODE_5_PIN)
#define CATHODE_6_PPS TOPPS(CATHODE_6_PIN)
#define CATHODE_7_PPS TOPPS(CATHODE_7_PIN)
#define CATHODE_8_PPS TOPPS(CATHODE_8_PIN)
#define CATHODE_9_PPS TOPPS(CATHODE_9_PIN)
#define CATHODE_0_PPS TOPPS(CATHODE_0_PIN)
#define CATHODE_COMMA_PPS TOPPS(CATHODE_COMMA_PIN)

// PWM parameters for cross-fading between digits. Cross-fading is accomplished by assigning one PWM4 (inverted) to the out-going digit and PWM3 to
// the incoming digit. The duty cycle of the PWMs is increased over a short interval resulting in one digit fading out while another fades in.
const int PWM_MAX = 250;        // The high limit of the PWM counter.
const int PWM_RAMP_STEPS = 10;  // The number of duty cycle step changes in the cross-fade.
const int PWM_RAMP_TIME = 350;  // The duration of the cross-fade, in ms.

const int PWM_RAMP_STEP_SIZE = PWM_MAX / PWM_RAMP_STEPS;
const int PWM_RAMP_STEP_INTERVAL = PWM_RAMP_TIME / PWM_RAMP_STEPS;

void InitPins()
{
    /*
     * I2C:
     * SCL = RB4
     * SDA = RB6
     * 
     * Address:
     * A0 = RA0
     * A1 = RA1
     * A2 = RC1
     * A3 = RC0
     */
    
    // I2C pins must be configured as inputs (§25.2.2.3)
    // Address pins are inputs
    TRISA = 0x03;
    TRISB = 0x50;
    TRISC = 0x03;

    // Clear the analog registers (§16.5)
    ANSELA = 0x00;
    ANSELB = 0x00;
    ANSELC = 0x00;
    
    // Enable weak pull-ups on address pins (§16.14.5)
    WPUA = 0x03;
    WPUC = 0x03;
    
    // Clear the GPIO pins
    PORTA = 0;
    PORTB = 0;
    PORTC = 0;
    
    // Set PPS input pins (§18.2, Table 18-1; §18.8.1)
    SSP1CLKPPS = PPS_INPUT(PPS_PORT_B, 4);
    SSP1DATPPS = PPS_INPUT(PPS_PORT_B, 6);

    // Set PPS output pins (§18.8.2)
    RB4PPS = PPS_OUT_SCL1;
    RB6PPS = PPS_OUT_SDA1;
}

void InitInterrupts()
{
    // Enable global and peripheral interrupts (§12.4)
    INTCONbits.GIE = 1;
    INTCONbits.PEIE = 1; 
}

void InitI2C()
{
    // Not relevant to clients (§25.4.4)
    SSP1STAT = 0x00;
    
    // 7-bit addressing client (§25.4.5)
    SSP1CON1 = 0x06;
    
    // Enable clock stretching (§25.4.6)
    SSP1CON2 = 0x01;
    
    // No start/stop interrupts (§25.4.7)
    SSP1CON3 = 0x00;
    
    // Set the client address and enable the full address mask (§25.4.2, §25.4.3)
    SSP1ADD = I2C_ADDRESS;
    SSP1MSK = 0xFE;

    // Enable Interrupts
    PIE1bits.SSP1IE = 1;

    // Enable the port (§25.4.5)
    SSP1CON1bits.SSPEN = 1;
}

void InitPWM()
{
    // Use the F_osc/4 source, as required for PWM (§21.10.5, §23.9)
    T2CLKCON = 0x1;
    
    // 250 tick counter reset results (§21.10.2)
    T2PR = (uint8_t)PWM_MAX;
    
    // Mode is free-running, period-pulse, software-gated (§21.10.4)
    T2HLT = 0x00;    
    
    // Enable the timer with a 1:16 pre-scaler (§21.10.3)
    T2CONbits.CKPS = 0;
    T2CONbits.ON = 1;

    // Invert PWM 4 (§23.11.1)
    PWM4CONbits.POL = 1;
    
    // Enable the PWMs (§23.11.1)
    PWM3CONbits.EN = 1;
    PWM4CONbits.EN = 1;
}

volatile uint8_t gDataI2C = 0xFF;
volatile uint8_t gNewDataI2C = 0;

// §25.2.3
void HandleI2C()
{
    // Clear the interrupt flag
    PIR1bits.SSP1IF = 0;
    
    if (!SSP1STATbits.D_nA)
    {
        //
        // Handle address message
        //
        
        // The buffer MUST be read to clear SSPxSTAT.BF (§25.2.3.6.1).
        uint8_t devNull = SSP1BUF;
        
        // If this is a read, immediately respond with the first byte (§25.2.3.7.2).
        if (SSP1STATbits.R_nW) SSP1BUF = gDataI2C;

        // Release the clock stretch (§25.2.3.6.1)
        SSP1CON1bits.CKP = 1;
    }
    else if (SSP1STATbits.BF)
    {
        //
        // Handle data - write
        //

        uint8_t buf = SSP1BUF;
        if (buf != gDataI2C)
        {
            gDataI2C = buf;
            gNewDataI2C = 1;
        }

        // Release the clock stretch. (§25.2.3.6.1)
        // The data sheet does not say to do this here, but the bus locks up 100% of the time if I don't.
        SSP1CON1bits.CKP = 1;
    }
}

void __interrupt() ISR()
{
    if (PIR1bits.SSP1IF == 1) HandleI2C();
}

void SetPwmDutyCycle(int dc)
{
    // §23.11.2
    PWM3DCH = PWM4DCH = (uint8_t)dc;
    PWM3DCL = PWM4DCL = 0;

    // Restart the PWM timer
    T2TMR = 0;
}

// Expands to an assignment that sets the PPS output for a given pin to one of three values:
//   If the pin # matches the selected digit, assign PWM 3 (increasing duty cycle, fade in)
//   Otherwise, if the pin # matches the previously selected digit, assign PWM 4 (decreasing duty cycle, fade out)
//   Otherwise, assign GPIO (off)
#define ASSIGN_PPS(PPS, X) PPS = (X == command.digit) ? PPS_OUT_PWM3 : (X == lastCommand.digit) ? PPS_OUT_PWM4 : 0;

void RampCathodePins(NixieCommand command)
{
    static NixieCommand lastCommand = { REFRESH_CATHODES_COMMAND };
    
    if (command._raw != lastCommand._raw)
    {
        SetPwmDutyCycle(0);

        // Set the digit drivers.
        ASSIGN_PPS(CATHODE_0_PPS, 0);
        ASSIGN_PPS(CATHODE_1_PPS, 1);
        ASSIGN_PPS(CATHODE_2_PPS, 2);
        ASSIGN_PPS(CATHODE_3_PPS, 3);
        ASSIGN_PPS(CATHODE_4_PPS, 4);
        ASSIGN_PPS(CATHODE_5_PPS, 5);
        ASSIGN_PPS(CATHODE_6_PPS, 6);
        ASSIGN_PPS(CATHODE_7_PPS, 7);
        ASSIGN_PPS(CATHODE_8_PPS, 8);
        ASSIGN_PPS(CATHODE_9_PPS, 9);

        // Ramp the duty cycle over time
        for (int pwm = 0; pwm <= PWM_MAX; pwm += PWM_RAMP_STEP_SIZE)
        {
            SetPwmDutyCycle(pwm);
            __delay_ms(PWM_RAMP_STEP_INTERVAL);
        }

        // Set the duty cycle > max for 100% duty cycle
        SetPwmDutyCycle(PWM_MAX + 1);
    }
    
    // Light the comma if requested, but only if a digit is also lit.
    CATHODE_COMMA_PIN = command.comma && (command.digit <= 9);
    
    lastCommand = command;
}

void UpdateCathodePins(NixieCommand command)
{
    static NixieCommand lastCommand = { REFRESH_CATHODES_COMMAND };
    
    if (command._raw != lastCommand._raw)
    {
        CATHODE_0_PIN = 0;
        CATHODE_1_PIN = 0;
        CATHODE_2_PIN = 0;
        CATHODE_3_PIN = 0;
        CATHODE_4_PIN = 0;
        CATHODE_5_PIN = 0;
        CATHODE_6_PIN = 0;
        CATHODE_7_PIN = 0;
        CATHODE_8_PIN = 0;
        CATHODE_COMMA_PIN = 0;
        
        switch (command.digit)
        {
            case 0: CATHODE_0_PIN = 1; break;
            case 1: CATHODE_1_PIN = 1; break;
            case 2: CATHODE_2_PIN = 1; break;
            case 3: CATHODE_3_PIN = 1; break;
            case 4: CATHODE_4_PIN = 1; break;
            case 5: CATHODE_5_PIN = 1; break;
            case 6: CATHODE_6_PIN = 1; break;
            case 7: CATHODE_7_PIN = 1; break;
            case 8: CATHODE_8_PIN = 1; break;
            case 9: CATHODE_9_PIN = 1; break;
        }
    }
    
    lastCommand = command;
}

// Scroll through all the cathodes for a minute. Apparently cathodes that aren't used can fail.
void RefreshCathodes()
{
    CATHODE_0_PIN = 0;
    CATHODE_1_PIN = 0;
    CATHODE_2_PIN = 0;
    CATHODE_3_PIN = 0;
    CATHODE_4_PIN = 0;
    CATHODE_5_PIN = 0;
    CATHODE_6_PIN = 0;
    CATHODE_7_PIN = 0;
    CATHODE_8_PIN = 0;
    
    for (uint8_t i = 0; i < 6; ++i)
    {
        CATHODE_9_PIN = 0;
        CATHODE_0_PIN = 1;
        __delay_ms(1000);
        
        CATHODE_0_PIN = 0;
        CATHODE_1_PIN = 1;
        __delay_ms(1000);
        
        CATHODE_1_PIN = 0;
        CATHODE_2_PIN = 1;
        __delay_ms(1000);
        
        CATHODE_2_PIN = 0;
        CATHODE_3_PIN = 1;
        __delay_ms(1000);
        
        CATHODE_3_PIN = 0;
        CATHODE_4_PIN = 1;
        __delay_ms(1000);
        
        CATHODE_4_PIN = 0;
        CATHODE_5_PIN = 1;
        __delay_ms(1000);
        
        CATHODE_5_PIN = 0;
        CATHODE_6_PIN = 1;
        __delay_ms(1000);
        
        CATHODE_6_PIN = 0;
        CATHODE_7_PIN = 1;
        __delay_ms(1000);
        
        CATHODE_7_PIN = 0;
        CATHODE_8_PIN = 1;
        __delay_ms(1000);
        
        CATHODE_8_PIN = 0;
        CATHODE_9_PIN = 1;
        __delay_ms(1000);
    }

    CATHODE_9_PIN = 0;
}

void main(void)
{
    InitClock();
    InitInterrupts();
    InitPins();
    InitPWM();
    
    // Give the address pins time to stabilize.
    __delay_ms(50);
    
    InitI2C();
    
    while (1)
    {
        if (gNewDataI2C)
        {
            NixieCommand command = { gDataI2C };
            gNewDataI2C = 0;
            
            if (REFRESH_CATHODES_COMMAND == command._raw) RefreshCathodes();
            else RampCathodePins(command);
        }
        
        __delay_ms(10);
    }
}

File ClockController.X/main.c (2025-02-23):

#include <xc.h>

#include "config_bits.h"
#include "clock.h"
#include "pins.h"
#include "i2c.h"
#include "serial.h"
#include "rtc.h"
#include "gps.h"
#include "bcd_utils.h"
#include "ap33772.h"
#include "timer.h"
#include "adc.h"
#include "pwm.h"
#include "boost_control.h"
#include "button.h"
#include "oled.h"
#include "ui.h"
#include "time_zone.h"
#include "nixie.h"

void __interrupt() ISR()
{
    // Dispatch interrupts to handlers (§12.9.6)
    if (PIR1bits.SSP1IF || PIR1bits.BCL1IF) I2C_HandleInterrupt();
    if (PIR1bits.RC1IF) GPS_HandleInterrupt();
    if (PIR1bits.TMR2IF) TimerInterruptHandler();
    if (PIR1bits.ADIF) AdcInterruptHandler();
    if (PIR0bits.IOCIF) Buttons_HandleInterrupt();
}

void EnableInterrupts()
{
    // Enable global and peripheral interrupts (§12.4)
    INTCONbits.GIE = 1;
    INTCONbits.PEIE = 1;    
    
    // Enable IOC interrupts (§17.2)
    PIE0bits.IOCIE = 1;

    // Enable MSSP Interrupts (§12.9.3)
    PIE1bits.SSP1IE = 1;
    PIE1bits.BCL1IE = 1;
    
    // Enable EUSART interrupts (§12.9.3)
    PIE1bits.RC1IE = 1;
    
    // Enable the TMR2 interrupt for tick counting
    PIE1bits.TMR2IE = 1;

    // Enable ACD interrupt
    PIR1bits.ADIF = 0;
    PIE1bits.ADIE = 1;
}

void SynchronizeTime()
{
    struct DateTime rtcTime;
    ConvertRtcToDateTime(&gRtc, &rtcTime);

    if (!TimesAreClose(&gGpsData.datetime, &rtcTime)) RTC_Set(&gGpsData.datetime);
}

void CheckGPS()
{
    if (gGpsData.updated)
    {
        if ('A' == gGpsData.status)
        {
            GPS_ConvertToLocalTime(gTimeZoneOffset);
            SynchronizeTime();
        }
        
        gGpsData.updated = 0;
    }
}

void HandleUserInteraction()
{
    if (gButtonState.deltaR >= 2) UI_HandleRotationCW();
    if (gButtonState.deltaR <= -2) UI_HandleRotationCCW();
    
    if (gButtonState.c.state && gButtonState.c.edge) UI_HandleButtonPress();
    
    gButtonState.rotation = ROTATION_NONE;
}

void main(void)
{
    InitClock();
    InitPins();
    
    TimeZone_Load();
    
    I2C_Host_Init();
    SerialInit();
    EnableInterrupts();
    
    Buttons_Init();
    
    // Give other devices (*cough*OLED*cough*) time to finish power-up.
    __delay_ms(50);
    
    OLED_Init();

#ifndef SKIP_PD
    if (!AP33772_Init()) while (1);
#endif
    
    InitTimer();
    InitAdc();
    InitPWM();
    BoostConverter_Init();
    
    // Power-on can be detected as a state change in buttons. That should have stabilized at this point, so reset the
    // edge states.
    Button_ResetEdges();
    
    // Exercise all the Nixie cathodes on startup.
    RefreshNixies();
    
    gGpsData.updated = 0;
    
    uint8_t frameCounter = 0;
    while (1)
    {
        HandleUserInteraction();
        
        if (frameCounter % 4 == 0)
        {
            RTC_Read();
            CheckGPS();

            UpdateNixieDrivers();
        }

        if (frameCounter % 10 == 0)
        {
            UI_TickSpinner();
            UI_Update();
        }
        
        ++frameCounter;
        __delay_ms(5);
    }
}

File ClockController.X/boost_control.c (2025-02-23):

#include "boost_control.h"
#include "timer.h"
#include "pwm.h"
#include "adc.h"

#include <xc.h>

#ifndef SKIP_PD
    // This defines the maximum allowed voltage (~200V).
    #define ADC_HI_LIMIT 787L
#else
    // ~12V if we're in debug and running off the PICKit.
    #define ADC_HI_LIMIT 47L
#endif

// The ADC returns a 10-bit value dividing the range 0mv to 4096mV evenly so mV/4 = ADC.
// The expected voltage from the voltage divider is ~2,835mV, which means the expected ADC value is ~709. This will
// vary with the exact resistance of the resistors in the voltage divider.
#define ADC_SP 721L
#define ADC_DEADBAND 5

// The voltage booster is controlled by changing the duty-cycle (DC) of the PWM signal driving it.
// By scaling the working DC value, we can have a working value with more granularity than the actual PWM allows. This
// can allow for some smoother control, depending on the algorithm.
#define PWM_DC_SCALAR 0x20
#define PWM_DC_100 ((TMR2_RESET << 2) * PWM_DC_SCALAR)
#define PWM_DC_MAX (uint16_t)(0.95 * PWM_DC_100)

// Control constants when over SP
#define PID_P_NUM_HI 1
#define PID_P_DENOM_HI 1
#define PID_DPWMDC_MAX_HI 0x1

// Control constants when below SP
#define PID_P_NUM_LO 1
#define PID_P_DENOM_LO 2
#define PID_DPWMDC_MAX_LO 0x1

static uint16_t gPwmDutyCycle = (uint16_t)(0.8 * PWM_DC_100);
static uint8_t gOverVoltageProtection = 0;

void BoostConverter_Init(void)
{
    SetPwmDutyCycle(gPwmDutyCycle);
}

void BoostConverter_Update(uint16_t adc)
{
#ifdef SKIP_PD
    return;
#endif
    
    // If save voltage levels are exceeded, stop the PWM.
    if (adc > ADC_HI_LIMIT)
    {
        PWM_Disable();
        gOverVoltageProtection = 1;
        
        return;
    }
    
    // While in OVP, wait for voltage to drop back to a save level before halving the PWM DC and restarting.
    if (gOverVoltageProtection)
    {
        if (adc > ADC_SP) return;
        
        gPwmDutyCycle /= 2;
        PWM_Enable(gPwmDutyCycle / PWM_DC_SCALAR);
        
        gOverVoltageProtection = 0;
        return;
    }
    
    int16_t cvError = (int16_t)adc - ADC_SP;
    uint16_t dPwmDc = 0;
    if (cvError > 0)
    {
        dPwmDc = (uint16_t)(cvError * PID_P_NUM_HI);
        //dPwmDc = (uint16_t)((cvError * PID_P_NUM_HI) / PID_P_DENOM_HI);
        if (dPwmDc > PID_DPWMDC_MAX_HI) dPwmDc = PID_DPWMDC_MAX_HI;
        
        if (dPwmDc <= gPwmDutyCycle) gPwmDutyCycle -= dPwmDc;
        else dPwmDc = 0;
    }
    else if (cvError < 0)
    {
        dPwmDc = (uint16_t)(-cvError * PID_P_NUM_LO);
        //dPwmDc = (uint16_t)((cvError * PID_P_NUM_LO) / PID_P_DENOM_LO);
        if (dPwmDc > PID_DPWMDC_MAX_LO) dPwmDc = PID_DPWMDC_MAX_LO;
        
        if (gPwmDutyCycle + dPwmDc < PWM_DC_100) gPwmDutyCycle += dPwmDc;
        else dPwmDc = PWM_DC_100;
    }
    
    SetPwmDutyCycle(gPwmDutyCycle / PWM_DC_SCALAR);
}

uint8_t BoostConverter_GetVoltage(void)
{
    // (4096 * ADC) / 1024 = mV on pin.
    // multiply by 63.5 to compensate for the voltage divider supplying the pin.
    // divide by 1000 to convert from mV to volts
    // This works out to (63.5 * (4096 / 1024)) / 1000 = 0.254, or ~(1/4 + 1/250).
    // The exact values used will depend on the precise value of the resistors.
    return (uint8_t)(gAdcCv / 4) - (uint8_t)(gAdcCv / 330);
}

uint16_t BoostConverter_GetDutyCycle(void)
{
    return gPwmDutyCycle / PWM_DC_SCALAR;
}

uint16_t BoostConverter_GetDutyCyclePct(void)
{
    return gPwmDutyCycle / (PWM_DC_100 / 100);
}

uint8_t BoostConverter_OverVoltageProtectionOn(void)
{
    return gOverVoltageProtection;
}

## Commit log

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2023-11-22 Added untested GPS code. I2C stuff still works.
2023-11-23 Faster oscillator setting so we're in a supported setting for the serial.
    [i2c.c, main.c]
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2023-11-24 A power supply daughter card I probably won't use
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2023-11-25 ISCP adapter board for programming the nixie driver board
2023-11-25 Fixed cut-out jumper being on the wrong circuit
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2023-11-29 Fixed 5V VRM, updated boost cap
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2023-11-29 Added missing I2C pullups
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2023-12-03 Added a streaming I2C write for OLED updates
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2023-12-06 Setting up final pin mapping and integrating behaviors
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2023-12-06 Added bus reset on error logic.
    [i2c.c]
2023-12-06 Functional breadboard stabilizes within 2% w/ 12V target
2023-12-09 Fixed race condition causing I2C to halt on a "stuck" S bit
    [i2c.c]
2023-12-09 Fixed auto cathode driving
    [adc.c, main.c]
2023-12-09 Fixed button logic
2023-12-09 Using the weak pull-up for the button pin
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2023-12-10 Switch to raw PWM values for duty cycle control.
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2023-12-16 Fixed DAT/CLK swapped on the connector
2023-12-23 Fixed incorrect pin read for button
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2023-12-23 Fixed ADC pin configuration getting overwritten by I2C
    [pins.c]
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2023-12-25 Disabling LVP and MCLR on the assumption this lets drop the MCLR filter circuit
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2024-01-28 Fixed shorted trace
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2024-01-28 Fixed DC connector polarity
2024-01-28 Fixed missing +5V connection
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2024-02-06 Moved power circuit to the left for USB C routing
2024-02-06 Fixed traces
2024-02-14 Fixed trace too close to pin pads. :(
2024-02-14 Fixed the other bad trace
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2024-02-27 Fixed mirror nixie footprint.
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2024-03-10 Flipped display header pin assignments
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2024-03-30 Fixed bad separator board design
2024-03-30 Fixed mounting hold positions
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2024-04-13 Fixed I2C write-then-read implementation
    [i2c.c, i2c_register_bits.h, main.c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]
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2024-04-16 Fixed broken solder mask/paste on USB-C connector
2024-04-16 Fixing backwards ISEN resistor
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2024-04-20 Added missing resistors, fixed net names
2024-04-20 Added missing CCx resistors and fixed Q5 pins
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2024-04-23 Fixed W/R bit not being set properly for callback writes.
    [i2c.c]
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2024-05-27 Fixed the ADC initialization
    [adc.c]
2024-06-08 Restart the AP33772 if it takes too long to get ready
    [ap33772.c]
2024-06-08 Fixed ADC PPS input config
    [adc.c]
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2024-06-25 Rotated display, and fixed init
    [oled.c]
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2024-06-25 Fixed level-shifting mosfet miswired
2024-06-25 Fixed MOSFET pins being mirrored in footprint
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2024-08-16 I2C fixes, including processor speed increase
    [main.c]
2024-08-27 Simplified OLED calls to fix stack overflow
    [ap33772.c, oled.c, ui.c]
2024-09-04 Fix the read-back handling
    [main.c]
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2024-10-15 Started converting controller to KiCad 8
    [Clock Controller.kicad_pcb, Clock Controller.kicad_sch, Clock_Controller_1.kicad_sch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]
2024-10-20 Cleaned up a bunch of labels
    [Clock_Controller_1.kicad_sch, Clock_Controller_3.kicad_sch, Clock_Controller_4.kicad_sch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]
2024-10-20 Renamed sub-sheets
    [+5 VRC.kicad_sch, Boost Converter.kicad_sch, Clock Controller.kicad_sch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]
2024-10-20 Updated most footprints
    [+5 VRC.kicad_sch, Boost Converter.kicad_sch, Clock Controller.kicad_pcb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]
2024-10-20 Aligned test points
    [Clock Controller.kicad_pcb]
2024-10-20 Deleted unused I2C pull-up resistors
    [Clock Controller.kicad_pcb, Headers.kicad_sch]
2024-10-20 Fixing design rule violations
    [Boost Converter.kicad_sch, Clock Controller.kicad_pcb]
2024-10-21 Fixed footprint issue with Q1
    [Clock Controller.kicad_pcb, USB PD.kicad_sch]
2024-10-21 Unsaved changes
    [Clock Controller.kicad_pcb, USB PD.kicad_sch]
2024-10-21 Initial KiCad import of Nixie Driver
    [Nixie Driver.kicad_pcb, Nixie Driver.kicad_sch]
2024-10-21 Migration from DipTrace. Updated symbols and footprints.
    [Nixie Driver.kicad_pcb, Nixie Driver.kicad_sch]
2024-10-21 Fixed header position
    [Nixie Driver.kicad_pcb, Nixie Driver.kicad_sch]
2024-10-21 Board cleanup
    [Nixie Driver.kicad_pcb]
2024-10-21 Deleted empty labels
    [Nixie Driver.kicad_pcb]
2024-10-21 Updated silkscreens
    [Nixie Driver.kicad_pcb]
2024-10-21 Unsaved changes.
    [Nixie Driver.kicad_pcb]
2024-12-01 More frequent ADC polling and over-voltage protection
    [HV Monitor.kicad_sch]
2024-12-01 Fixed display switching off at startup
    [ui.c]
2024-12-01 Revert back to TMR2
    Using PWM3 wasn't triggering the ADC interrupts.
    It also doesn't seem to like running off TMR2 with no post-scaller
    [adc.c, main.c]
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2024-12-02 Fixed spurious UI inputs on power-up
    [main.c]
2024-12-02 Fixed OVP warning placement
    [ui.c]
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2024-12-14 Separator board in KiCad
    Added a second resistor because both lamps won't light simultaneously with one.
    [Separator.kicad_pcb, Separator.kicad_sch]
2024-12-14 Converted ICSP adapter to KiCad
    [ICSP Adapter.kicad_pcb, ICSP Adapter.kicad_sch]
2024-12-14 Converted to native KiCad footprints and symbols
    [ICSP Adapter.kicad_pcb, ICSP Adapter.kicad_sch]
2024-12-14 Modified ICSP header footprint
    [ICSP Adapter.kicad_pcb, ICSP Adapter.kicad_sch]
2024-12-14 Rounded PCB corners
    [ICSP Adapter.kicad_pcb]
2024-12-17 Squashed commit of the following:
    commit ceaeb3480282281a1da8399835ad34ef6f77221f
    Author: Fish-in-a-Barrel <aaron.m.johnson@gmail.com>
    Date: Tue Dec 17 16:05:15 2024 -0600
    Fixed stencil alignment holes.
    commit 4ecd21d86c7d5893fedbf0090fcecf692d6aaa64
    Author: Fish-in-a-Barrel <aaron.m.johnson@gmail.com>
    Date: Tue Dec 17 15:40:31 2024 -0600
    Reduced resistor size to 0805
    commit 0f75641f3a121fcc031c4463333a2dd006798184
    Author: Fish-in-a-Barrel <aaron.m.johnson@gmail.com>
    Date: Tue Dec 17 15:28:49 2024 -0600
    drc updates
    commit d9341e6379937dfeab207db1969b1642027c2ff2
    Author: Fish-in-a-Barrel <aaron.m.johnson@gmail.com>
    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
    [Nixie Driver.kicad_pcb, Nixie Driver.kicad_sch]
2024-12-18 Starting Display Board in KiCad
    [Display Board.kicad_pcb, Display Board.kicad_sch, Nixie Headers.kicad_sch]
2024-12-18 Components placed
    [Display Board.kicad_pcb, Display Board.kicad_sch]
2024-12-18 KiCad display board completed
    [Display Board.kicad_pcb, Display Board.kicad_sch]
2024-12-18 Forgot to save again. (╯°□°）╯︵ ┻━┻
    [Display Board.kicad_pcb]
2024-12-18 Prettying up the board a bit.
    [Display Board.kicad_pcb]
2024-12-18 Cleaned up the copper pour
    [Display Board.kicad_pcb]
2024-12-18 Rotated GPS module for better antenna routing
    [Display Board.kicad_pcb, Display Board.kicad_sch]
2024-12-18 Production files generated
    [Display Board.kicad_pcb]
2024-12-18 Separated the grounds so the test harness will still work.
    [Nixie Driver.kicad_pcb, Nixie Driver.kicad_sch]
2024-12-25 Added holes for the antenna holder
    [0.91in OLED.step, Display Board.kicad_pcb, Display Board.kicad_sch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]
2024-12-25 Added JLCPCB order number placeholder.
    [Display Board.kicad_pcb]
2025-01-14 Move resistor back to the anode
    [Nixie Driver.kicad_pcb, Nixie Driver.kicad_sch]
2025-01-15 Cleaned up traces.
    [Nixie Driver.kicad_pcb]
2025-01-15 Upsized current-limiting resistor
    [Nixie Driver.kicad_pcb, Nixie Driver.kicad_sch]
2025-01-30 Fixed digits never illuminating
    [main.c]
2025-02-01 Added small negative solder mask expansion to MCU
    [Nixie Driver.kicad_pcb]
2025-02-02 Fixed comma inhibit logic
    [main.c]
2025-02-04 Added Nixie Driver Tester hardware (incomplete)
    [5V VRM.kicad_sch, Boost Converter.kicad_sch, Button.kicad_sch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]
2025-02-19 Fixed first command ignored if zero
    [main.c]
2025-02-23 Squashed commit of the following:
    commit 2b46fe7b71221aaec37e9e0d3aee2aa990eb3e65
    Date: Sat Feb 22 19:06:52 2025 -0600
    Remove unused files
    commit 1bf26ed803d2ce20de53ef10f76724fbb63c3649
    Date: Sat Feb 22 19:06:43 2025 -0600
    Remove unneeded weak pull-up code
    commit d0962e6024b029914122c4d3826576131f993fcf
    Date: Sat Feb 22 18:29:17 2025 -0600
    Fixed section markers
    commit 4d6b264a1fd1dfaf1ab4948834c952908a3fa2a3
    Date: Tue Jan 14 15:01:49 2025 -0600
    Enablin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
    [adc.c, boost_control.c, main.c]
2025-03-06 Fixed address instability
    Weak pull-up not being enabled on address pins caused some Nixies to sometimes miss some address bits.
    [main.c]
2026-04-02 Replacing many thin traces with poured zones.
    [+5 VRC.kicad_sch, Boost Converter.kicad_sch, Clock Controller.kicad_pcb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]
2026-04-02 Moved the VRM for shorter traces
    [Clock Controller.kicad_pcb]
2026-04-02 More zones
    [Clock Controller.kicad_pcb]
2026-04-04 Small layout adjustments
    [Clock Controller.kicad_pcb]
2026-04-04 Simplified I2C cutoff
    [Clock Controller.kicad_pcb, Headers.kicad_sch]
2026-04-04 Moved C3
    [Clock Controller.kicad_pcb]
2026-04-04 Moved the VRM closer to the main load
    [Clock Controller.kicad_pcb]
2026-04-04 Down-sized a bunch of resistor packags
    [Clock Controller.kicad_pcb, USB PD.kicad_sch]
2026-04-04 Cleanup of the silkscreens.
    [Clock Controller.kicad_pcb]
2026-04-04 Added stencil alignment holes
    [Clock Controller.kicad_pcb]
2026-04-04 Relocated the test points
    [Clock Controller.kicad_pcb]
2026-04-04 Add JLPCB order placeholder
    [Clock Controller.kicad_pcb]
2026-04-04 4-layer board
    [Clock Controller.kicad_pcb]
2026-04-11 Swapped out a bad footprint that was missing layers
    [Clock Controller.kicad_pcb]
2026-04-11 Fixed some broken 3d model references
    [Clock Controller.kicad_pcb]
2026-04-11 Updated some footprints
    [Clock Controller.kicad_pcb, Headers.kicad_sch, Rotary Input.kicad_sch]
2026-04-15 Fixed bad pull-up design of I2C cutoff transistors
    [Clock Controller.kicad_pcb, Headers.kicad_sch, Microcontroller.kicad_sch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]
2026-04-15 Updated version number on board
    [Clock Controller.kicad_pcb]
2026-04-29 Kicad 10
    [+5 VRC.kicad_sch, Boost Converter.kicad_sch, Clock Controller.kicad_pcb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]
